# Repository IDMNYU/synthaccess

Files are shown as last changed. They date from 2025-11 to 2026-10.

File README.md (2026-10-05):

# synthaccess

#### syn?a3ess

A repository of research around and resources for synthesizer (and other audio technology) accessibility.

[ABILITY Project](http://ability.nyu.edu) / [Integrated Design & Media](http://idm.engineering.nyu.edu)   
New York University

Featuring the work of:
- [Ciarra Black](https://www.ciarrablack.com/)
- [Jason Dasent](https://www.jasondasent.com/)
- [R. Luke DuBois](https://lukedubois.com/), Faculty Lead, MIDI Speech Synth
- [Stefanie Koseff](https://www.stefaniekoseff.com/), Faculty Lead, Tactile Synth Guides
- [Tommy Martinez](https://thomasjohnmartinez.com/)
- [Madeline Mau](https://www.linkedin.com/in/madeline-mau-b01b9739b/)
- [Willie Payne](https://williepayne.com/)
- [Lauren Race](https://laurenrace.com/)
- [Izabella Rodrigues](https://www.izabellarodrigues.com/)
- [Jason Wallach](https://www.linkedin.com/in/jason-wallach-1340a612a/)
- [Moira Zhang](https://moirazhang.com/)

Projects:
- **[MIDItoSpeech](./MIDItoSpeech/)** : a speech synthesizer to vocalize parameters from a music technology device (synthesizer, effects processor, etc.) that transmits its state via MIDI.
- **[tactileSynthGuides](./tactileSynthGuides/)** : a design guide and library of swell-form printable tactile guides for synthesizers.
- **[brailleOverlays](./brailleOverlays/)** : guidelines for adding braille labels and overlays to physical synthesizers.
- **[tactileModular](./tactileModular/)** : a set of design resources for tactile affordances for modular synthesizers.

---

**SynthAccess** is a multi-pronged open source initiative around accessibility for Blind / Low Vision (BLV) musicians who use synthesizers and related equipment. This includes standards for braille labeling and tactile guides, software to generate synthesized speech as affordances are moved on the devices, and 3D printed alternatives to knobs and jacks to make them distinguishable by feel.

Modern music technology is challenging from an accessibility standpoint as it often features ocularcentric design patterns that use screens, LEDs to indicate state, and affordances such as rotary controls and soft buttons that only provide visual feedback.

For this project, we leverage two trends in synthesizer equipment: 
- Historical synthesizer designs employ *analog* circuitry, and have a design layout that is one affordance per function, which means that there are knobs, buttons, switches, sliders, and so forth that map to one specific parameter on the instrument. There are many modern synthesizers that either emulate this design approach or are recreations of historical equipment. This allows us to create overlay systems and tactile guides that allow a user to navigate a synthesizer user interface by touch.
- Modern synthesizers often employ microprocessors that *transmit the state* of their controls as they are being manipulated, typically using the MIDI protocol introduced in 1983 for digital communication among music technology equipment. This allows us to use computers and microcontrollers to listen to user actions performed on a synthesizer and create speech-based, haptic, refreshable braille, and other accessible interfaces without any change to the hardware.

Over the past year, we have developed a number of exemplar design interventions to assist BLV users with synthesizers. This work was undertaken as part of a larger initiative around making the [NYU Tandon IDM Audio Lab](https://idmnyu.github.io/audiolab/) accessible for users with disabilities, as well as work done in collaboration with the [FMDG Music School](https://fmdgmusicschool.org/) and a number of US music conservatories towards creating contemporary standards around music education for BLV students. In addition, we have been partnering with the [Focusrite Group](https://focusriteplc.com/) to adopt our standards to three of their synthesizer brands ([Sequential Circuits](https://sequential.com/), [Oberheim](https://oberheim.com/), and [Novation](http://novationmusic.com/)). We have also developed overlays for various other historical and contemporary synthesizers made by ARP, Roland, Nensén Electronics, and the Black Corporation.

We are interested in collaborating with industry partners and organizations to further develop our proposed designs and have them adopted as standards that could be integrated into the design and manufacturing stage for commercial synthesizers. We are also interested in further developing these tools for other music technology devices, and partnering with enthusiasts in the community to develop assets for vintage, open source, and DIY equipment.

We believe there is an opportunity to create strong consensus in the music technology industry that accessibility matters and can be viewed as a focal point of *collaboration*, not *competition*. To this end, this work is being published as free and open to the public under open-source software (MIT) and document copyright (CC BY-NC-SA 4.0) licenses.

If you're interested in working with us, please get in touch by writing Luke (dubois at nyu dot edu).

---

*A note to screen reader users:* some of the pages in this site use Grade 2 braille examples. These examples will be encoded in a way that may prevent a screen reader from reading them correctly. For example, the Grade 2 braille equivalent of **synthaccess** - this project's name - is <bl>syn?a3ess</bl>. In each case, a regular transliteration will be provided as well.

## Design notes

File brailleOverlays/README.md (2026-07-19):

# brailleOverlays

#### brlov}lays

Part of [synthaccess](../README.md)

[ABILITY Project](http://ability.nyu.edu) / [Integrated Design & Media](http://idm.engineering.nyu.edu)   
New York University

Files:
- README.md - this file
- [synths](https://github.com/IDMNYU/synthaccess/tree/main/brailleOverlays/synths) - folder containing vector synth overlays with braille mappings
    - [Human Comparator TTSH](https://raw.githubusercontent.com/IDMNYU/synthaccess/refs/heads/main/brailleOverlays/synths/TTSH.svg)
    - [Sequential Circuits Prophet 6 Desktop](https://raw.githubusercontent.com/IDMNYU/synthaccess/refs/heads/main/brailleOverlays/synths/Prophet6.svg)
- img - folder containing example images

**brailleOverlays** is a set of design guidelines and examples for adding braille lettering to synthesizers. 

## Introduction

If your synthesizer is "one affordance per function", one of the simplest and most effective ways to add tactile accessibility for Blind / Low Vision users is to label the synthesizer with braille. Below, we outline three methods (from simple and inexpensive to somewhat complex) for doing this.

[Braille](https://en.wikipedia.org/wiki/Braille) is a [standard](https://brailleauthority.org/size-and-spacing-braille-characters) tactile writing system invented in 1824 that uses a two column by three row grid of six dots for each character. The braille system not only specifies the layout of these dots for each character in the writing system, but also defines the characters' nominal dot sizing and spacing. In other words, there's no such thing as "winging it" when it comes to your braille size. There's just braille. With standard braille fonts, such as David Rakowski's [Braille TTF](https://www.1001fonts.com/braille-font.html) and [Swell Braille](https://www.ffonts.net/Swell-Braille.font.download), you can set your design software to 24 point and it will be within range. There are [standard mappings](https://en.wikipedia.org/wiki/International_uniformity_of_braille_alphabets) for common writing systems across the world. Languages that use logographic writing systems (such as [Chinese](https://en.wikipedia.org/wiki/Mainland_Chinese_Braille)) will use a phonetic alphabet to create a braille mapping.

Grade (or Level) 1 braille defines a [basic mapping](https://brailleaustralia.org/wp-content/uploads/2013/09/braillecharacters.pdf) for the alphabet, numbers, and punctuation. Grade 2 braille has [contractions](https://www.teachingvisuallyimpaired.com/uploads/1/4/1/2/14122361/ueb_braille_chart.pdf), leveraging context and unused characters to reduce common words, letter combinations, and syllables to fewer characters. Grade 1 braille is standardized by *character set* (e.g. the Roman alphabet versus Cyrillic), whereas Grade 2 braille is specific to the *language* being written (e.g. English vs. French). Free software such as [BrailleBlaster](https://www.brailleblaster.org/) can be used to convert text into braille that includes these Grade 2 contractions.

If you use Grade 2 braille, you can save space. For example, the phrase:

*"Some little children adding 2+2 might count it as 22, not 4."*

can be converted using Grade 2 braille to:

<bl>,"s ll *n add+ #b"6#b mi<t c.t x z #bb1 n #d4</bl>

<br>

This certainly saves space (46 characters instead of 61). However, a user who reads braille in a language other than English might not be able to read it.

## Option #1: Braille tape

The simplest way to add braille to a synthesizer is to use a low cost braille labeller (such as [this one](https://www.maxiaids.com/product/reizen-rl-350-braille-labeler)) and some adhesive-backed labeling tape (such as [this](https://www.amazon.com/NineLeaf-Compatible-3D-Embossing-Organizer/dp/B0C3MGZKYH/?th=1)). You can then punch out braille labels and apply them directly to your synthesizer's front panel. If you use clear labels, you can place the braille labels over the printed labels on the synthesizer. You can also create braille labels manually, using a [braille stylus](https://carroll.org/product/single-line-slate-w-stylus/) on dymo tape or any adhesive paper.

An alternative to this method is to print out sheets of braille on an embossing printer (such as [this one](https://viewplus.com/product/vp-columbia-2/#product-more-info)) using sticker paper, which you then cut out and affix to the device. You can use [BrailleBlaster](https://www.brailleblaster.org/) and the [Braille TTF](https://www.1001fonts.com/braille-font.html) typeface to experiment with this method.

Depending on the density of controls on your synthesizer, you may not be able to label everything (see [mappings](#mappings), below, on some ideas for shorthand). For synthesizers where it's not practicable to create a braille label for every single affordance, you could consider labelling the section headings of different areas of the synth (oscillator, filter, mixer, etc.), and then create a [tactile guide](../tactileSynths) to cover the details.

## Option #2: Labels on an overlay

While it's great to add labels directly to your equipment, two issues might occur. First, the synthesizer surface might not take well to adhesive labels (for example, if the face plate on the synthesizer is powder-coated metal). Second, you might be worried about the labels damaging your synthesizer (for example, if you have a vintage equipment where adhesives might cause wear on the visual labels underneath).

A great solution for all of this is to cut a **plexiglass overlay** for your synthesizer, and then affix the braille to the overlay. You can often make these overlays simply if you have access to a laser cutter; you can use pre-cut plexiglass (we use [0.040" clear colorless acrylic](https://www.canalplastic.com/products/clear-colorless-0-040-acrylic-sheet?variant=37615076302)) to make clear, thin sheets that can sit on top of the synthesizer's face, with holes cut in place for switches, buttons, knobs, etc.

The best overlays have ample space for all of the affordances (knobs, switches, sliders, jacks) on the synthesizer, but can still be affixed to the synth face in an easy manner. One way to do this is to add cutout points for the front panel mounting screws and make those circles small enough that you can use the screws to mount the plexi overlay and secure it it to the synth. Additionally, potentiometers often have knobs or slider caps that can be removed, so the cutout can be narrower, as it only needs to accommodate the shaft of the pot.

To make an overlay, there are a bunch of options:

1. Many commercial manufacturers provide line-art renderings of their front panels (on their websites, in PDF documentation, etc.) that can be imported into a vector design program (e.g. [Inkscape](https://inkscape.org/), Adobe Illustrator, CorelDRAW) and traced over to make a laser cuttable overlay. You can also write the manufacturer's support group and explain that you're making an accessibility overlay for one of their synths and would love a reference CAD file to work from - there's a good chance they'll help you out.
2. You can take a high resolution photograph of your synth and trace over it. Be careful for skewing / pincushioning artifacts from your camera not being face on with the synth.
3. You can use a 3D scanning app (such as Polycam or 3D Scanner App) to make a scan of your synthesizer's front panel and import it into 3D modelling software (such as [Blender](https://www.blender.org/)) that knows how to export a 2D vector slice of a 3D model. 2D vector software that knows how to create slices from 3D assets (Illustrator, Inkscape) can do this as well.
4. If the synthesizer is reasonably small, you can place it face-down on a scanner (or a photocopier with a scanning function). You can then create a layer and draw cutouts for your overlay.

With any of these methods, we recommend doing a test cut first on cardboard to make sure everything fits properly. Once you've got your overlay fitted, you can add your braille adhesive labels and they should stick well. As an added bonus, you now have a protective cover for your synthesizer!

## Option #3: UV Print the braille directly onto an overlay

If you're going to create an overlay for your synth, you can UV print the braille (as well as dividers and any other tactile graphics) onto the acrylic directly by using a commercial UV flatbed printer. Commercial print shops will often have UV printing service; for example, in the USA, if a print shop advertises that they can do "ADA signage", then you're probably in the right place. There may be print services in your community that are able to do a full-service project - they will source the acrylic, laser cut the overlay, and do the braille printing all in one go. It's our experience that many UV printers will typeset braille within their own software or work with design software customized for sign printing that knows how to typeset braille, such as [Flexi Design](https://www.thinksai.com/products-flexi-design/).

## Examples

The synthesizers we have created overlays for in the [IDM Audio Lab](https://idmnyu.github.io/audiolab/) are contained in the [synths](https://github.com/IDMNYU/synthaccess/tree/main/brailleOverlays/synths) folder of this repository as layered SVG files. 
1. The 'overlay' layer contain the laserable cutout.
2. The 'braille' layer contains braille labels in the [Braille TTF](https://www.1001fonts.com/braille-font.html) font. These labels can be made with a braile labeler, printed using an embossing printer, or directly printed onto an overlay using a UV printer.
3. The 'dividers' layer contains suggested dividers for different sections of the synthesizer. These can be made in a variety of ways; the simplest is to use the <bl>a</bl> / 'a' letter on a braille labeller and then turn the tape to the correct orientation. As with the above, you can also directly print this onto an overlay using a UV printer.

For example, here is the overlay developed by Moira Zhang for our [TTSH](https://idmnyu.github.io/audiolab/arp.html#ttsh) (a DIY ARP 2600 clone, developed by Jon Nensén).

This image shows the front panel of the TTSH:
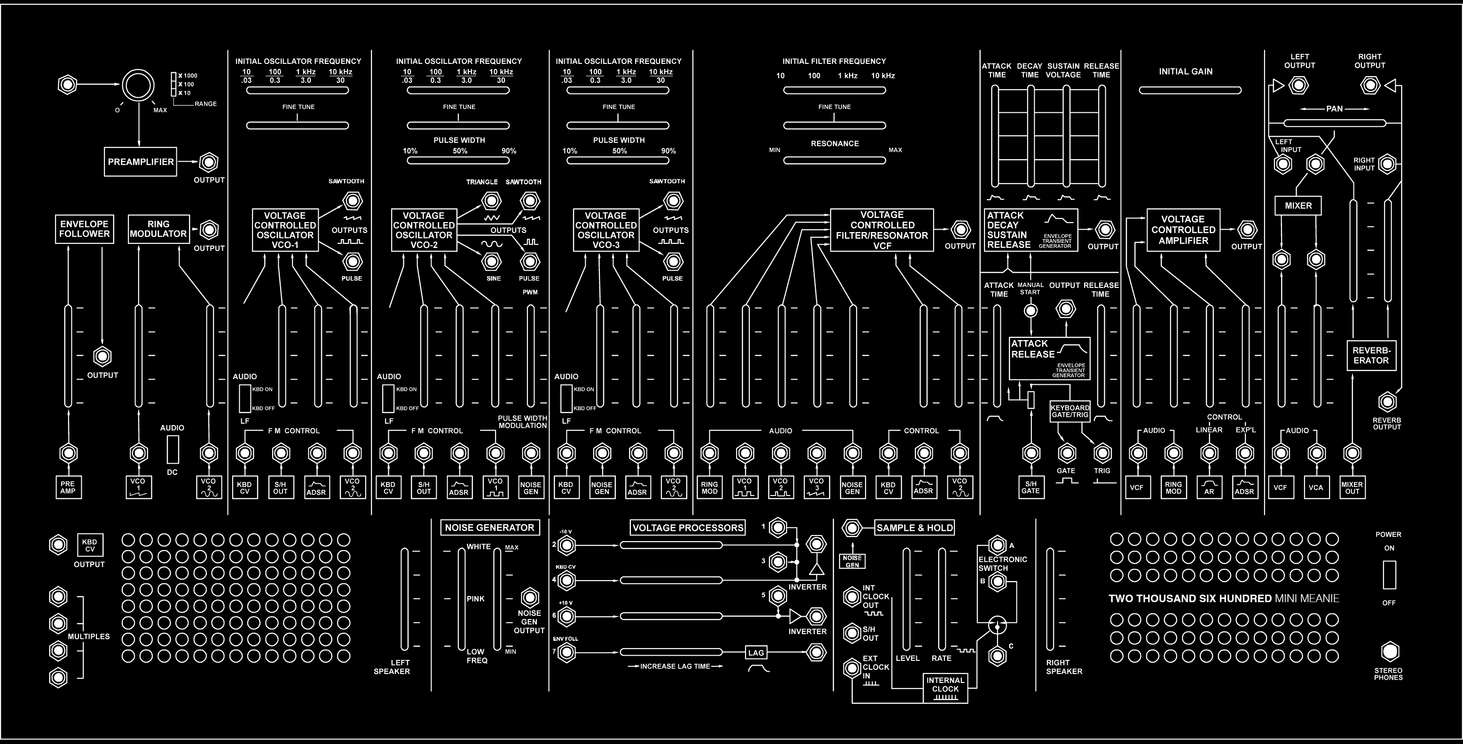
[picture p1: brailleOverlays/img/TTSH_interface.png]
TTSH visual interface

This image shows the full composite overlay of the TTSH, including interface channels, braille, and dividers:
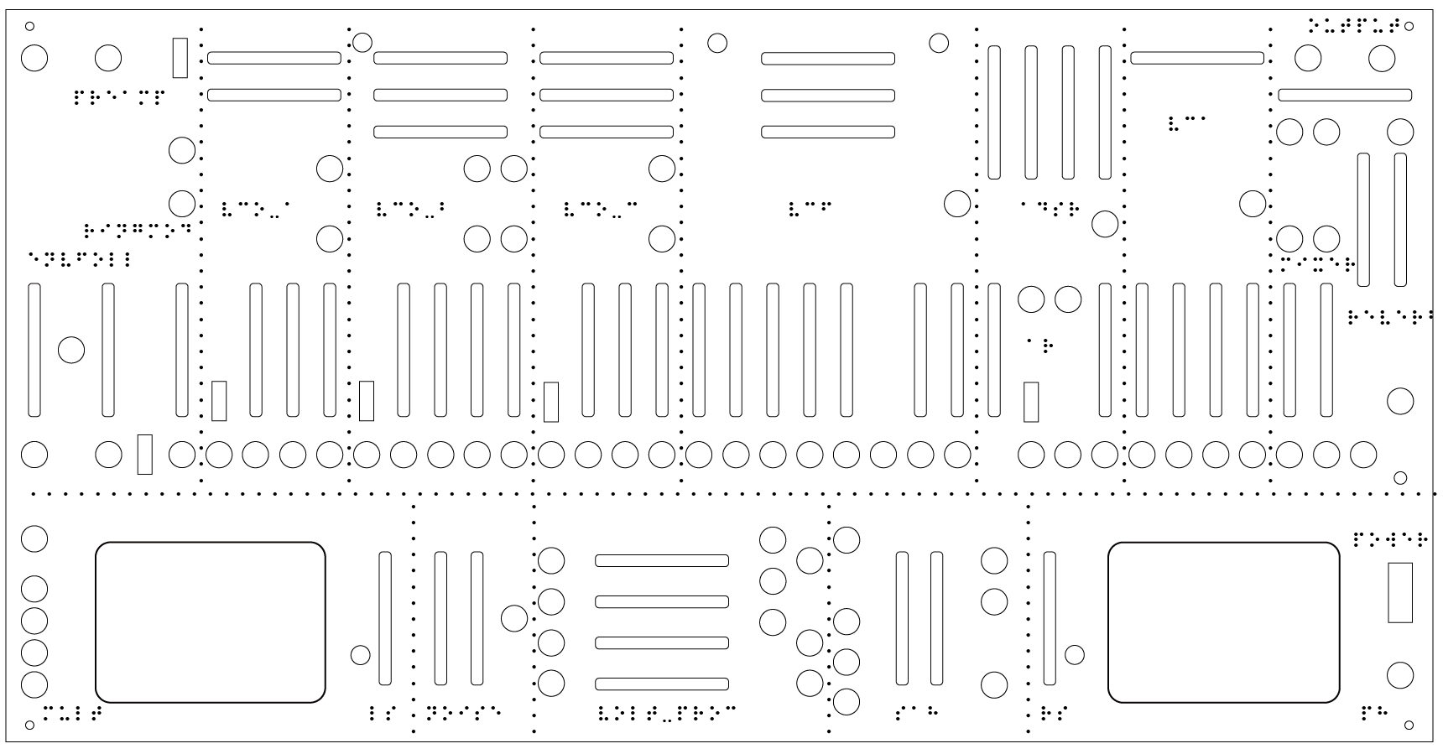
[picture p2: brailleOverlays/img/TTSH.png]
TTSH full overlay, with dividers and braille

This is the TTSH interface image used for laser cutting the overlay. Note the smaller circles - those are the front-panel screw points, not modular jacks - we used those to fix the overlay. We removed the knob for the microphone gain and the caps for the slide potentiometers before putting the panel on.
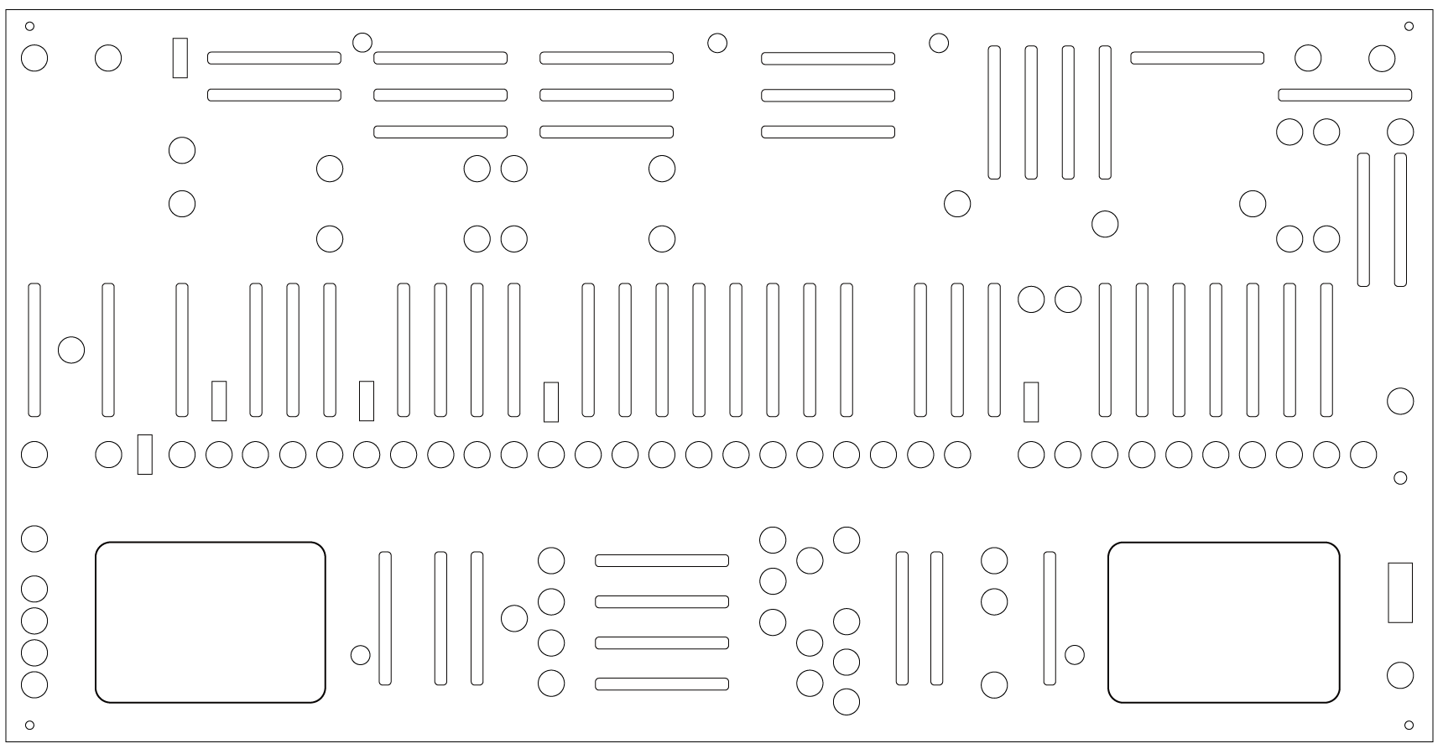
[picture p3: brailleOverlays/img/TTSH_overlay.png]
TTSH laser overlay

These are the TTSH braille labels by themselves. You could use a braille labeller to make these.
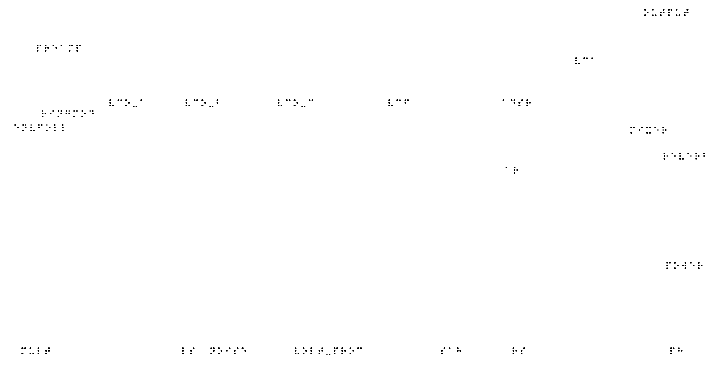
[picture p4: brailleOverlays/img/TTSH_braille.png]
TTSH braille labels

Finally, these show divider labels for the TTSH made using braille dots. You can make a long adhesive line of them, cut them to size with scissors, and apply them to give a tactile sense of the boundaries between the different modules on the synth.
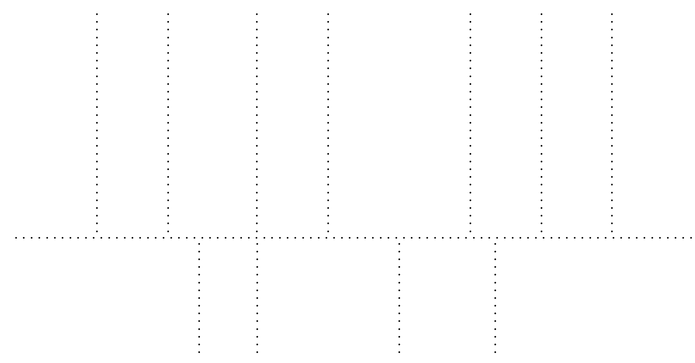
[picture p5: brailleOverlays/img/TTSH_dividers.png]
TTSH divider labels


If you would like to contribute to this project or have an overlay file you've done, please get in touch.

## Suggested Mappings

When designing braille overlays for physical synthesizers, space may be at a premium, so shorhands, abbreviations, contractions, and use of Grade 2 braille will be super useful for labelling things. Below are some suggested mappings for common synthesizer controls if you have space for 2, 3, or 4 braille characters. 

As mentioned above, for more high density interfaces, a great solution is to create a tactile guide. The [tactileSynths](../tactileSynths) part of this repository will help you get started.

### General Synthesizer Terminology

| Label | 2 | 3 | 4 |
| ----- | ----- | ----- | ----- |
| <bl>p{}</bl><br>Power | <bl>pr</bl><br>pr | <bl>pwr</bl><br>pwr | <bl>powr</bl><br>powr |
| <bl>h1dph"os</bl><br>Headphones | <bl>ph</bl><br>ph |  | <bl>phns</bl><br>phns |
| <bl>voltage-3troll$ oscillator</bl><br>Voltage-Controlled Oscillator | <bl>vo</bl><br>vo | <bl>vco</bl><br>vco | |
| <bl>voltage-3troll$ filt}</bl><br>Voltage-Controlled Filter | <bl>vf</bl><br>vf | <bl>vcf</bl><br>vcf |  |
| <bl>voltage-3troll$ amplifi}</bl><br>Voltage-Controlled Amplifier | <bl>va</bl><br>va | <bl>vca</bl><br>vca |  |
| <bl>l{ frequ5cy oscillator</bl><br>Low Frequency Oscillator | <bl>lf</bl><br>lf | <bl>lfo</bl><br>lfo |  |
| <bl>s9e wave</bl><br>Sine Wave | <bl>sn</bl><br>sn | <bl>s9e</bl><br>sine |  |
| <bl>triangle wave</bl><br>Triangle Wave | <bl>tr</bl><br>tr | <bl>tri</bl><br>tri |  |
| <bl>sawtoo? wave</bl><br>Sawtooth Wave | <bl>sa</bl><br>sa | <bl>saw</bl><br>saw |  |
| <bl>squ>e wave</bl><br>Square Wave | <bl>sq</bl><br>sq | <bl>sqr</bl><br>sqr |  |
| <bl>noise generator</bl><br>Noise Generator | <bl>no</bl><br>no | <bl>noi</bl><br>noi | |
| <bl>attack rel1se</bl><br>Attack Release | <bl>ar</bl><br>ar | | |
| <bl>attack decay su/a9 rel1se</bl><br>Attack Decay Sustain Release | | | <bl>adsr</bl><br>adsr |
| <bl>5velope g5}ator</bl><br>Envelope Generator | <bl>eg</bl><br>eg | <bl>env</bl><br>env |  |
| <bl>sample & hold</bl><br>Sample and Hold | <bl>sh</bl><br>sh | <bl>sah</bl><br>sah | |
| <bl>syn*ronize</bl><br>Synchronize | <bl>sy</bl><br>sy | <bl>syn</bl><br>syn | <bl>sync</bl><br>sync |
| <bl>5velope foll{}</bl><br>Envelope Follower | <bl>ef</bl><br>ef | <bl>efl</bl><br>efl |<bl>enfl</bl><br>enfl |
| <bl>r+ modulator</bl><br>Ring Modulator | <bl>rm</bl><br>rm | <bl>r+m</bl><br>ringm |<bl>r+md</bl><br>ringmd |
| <bl>mix}</bl><br>Mixer | <bl>mx</bl><br>mx | <bl>mxr</bl><br>mxr |<bl>mix}</bl><br>mixer |
| <bl>frequ5cy</bl><br>Frequency | <bl>fr</bl><br>fr | <bl>frq</bl><br>frq |<bl>freq</bl><br>freq |
| <bl>filt}</bl><br>Filter | <bl>fi</bl><br>fi | <bl>fil</bl><br>fil |<bl>fltr</bl><br>fltr |
| <bl>l{ pass filt}</bl><br>Low Pass Filter | <bl>lp</bl><br>lp | <bl>lpf</bl><br>lpf | |
| <bl>hi< pass filt}</bl><br>High Pass Filter | <bl>hp</bl><br>hp | <bl>hpf</bl><br>hpf | |
| <bl>b& pass filt}</bl><br>Band Pass Filter | <bl>bp</bl><br>bp | <bl>bpf</bl><br>bpf | |
| <bl>not* filt}</bl><br>Notch Filter | <bl>nf</bl><br>nf | | <bl>not*</bl><br>notch |

### Serge Modular Names

Serge Modular systems have specific acronyms and abbreviations for canonical modules (as seen in e.g. the [1983 sales catalog](https://docs.google.com/viewer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)) that are short enough to be used as braille labels. A mapping table is below.

**1973-75 "Paperface" Modules:**

| Module | Label |
| ----- | ----- |
| Adapter | <bl>adp</bl><br>ADP |
| Dual Processor | <bl>prc</bl><br>PRC |
| Envelope Generator | <bl>env</bl><br>ENV |
| Filter | <bl>vcf</bl><br>VCF |
| Gate | <bl>vca</bl><br>VCA |
| Negative Slew | <bl>neg</bl><br>NEG |
| Noise Source | <bl>noi</bl><br>NOI |
| Oscillator | <bl>vco</bl><br>VCO |
| Peak & Trough | <bl>p&t</bl><br>P&T |
| Preamp | <bl>pre</bl><br>PRE |
| Reverb | <bl>rvb</bl><br>RVB |
| Positive Slew | <bl>pos</bl><br>POS |
| Programmer | <bl>prg</bl><br>PRG |
| Ring Modulator | <bl>r+</bl><br>RING |
| Sequencer | <bl>seq</bl><br>SEQ |
| Smooth Function / Stepped Function VC Generator | <bl>ssg</bl><br>SSG |
| (Triple) Bi-Directional Router | <bl>tbs</bl><br>TBS |
| (Triple) Comparator | <bl>com</bl><br>COM |
| Triple Waveshaper | <bl>tws</bl><br>TWS |

**3rd/4th Generation Modules:**

| Module | Label |
| ----- | ----- |
| Active Processor | <bl>acpr</bl><br>ACPR |
| Analog Shift Register | <bl>asr</bl><br>ASR |
| Control Module | <bl>c/m</bl><br>C/M |
| Divide-by-N Comparator | <bl>ncom</bl><br>NCOM |
| Dual 3-Input Audio Mixer | <bl>mix</bl><br>MIX |
| Dual Channel Stereo Mixer | <bl>dcsm</bl><br>DCSM |
| Dual Schmitt Trigger | <bl>str</bl><br>STR |
| Dual Stereo Panner Channel | <bl>pan</bl><br>PAN |
| Dual Universal Slope Generator | <bl>dsg</bl><br>DSG |
| Dual VC Phaser | <bl>2pha</bl><br>2PHA |
| Dual VC Transient Generator | <bl>dtg</bl><br>DTG |
| Dual VCA | <bl>2vca</bl><br>2VCA |
| Envelope Detector | <bl>env</bl><br>ENV |
| Extended ADSR Envelope Generator | <bl>adsr</bl><br>ADSR |
| Extended Range VCFQ  | <bl>vcfs</bl><br>VCFX |
| Four Input Stereo Mixer/Panner | <bl>mxp</bl><br>MXP |
| Frequency Shifter | <bl>frs</bl><br>FRS |
| Matrix Mixer  | <bl>max</bl><br>MAX |
| Multi-Channel Quadraphonic Mixer | <bl>qmx</bl><br>QMX |
| Multi-Channel Stereo Panner | <bl>stx</bl><br>STX |
| N-Voice Controller | <bl>nvc</bl><br>NVC |
| New Timbral Oscillator | <bl>nto</bl><br>NTO |
| Pitch and Envelope Follower | <bl>pef</bl><br>PEF |
| Preamp Detector | <bl>prnv</bl><br>PRNV |
| Precision VCO | <bl>pco</bl><br>PCO |
| Quad Panner Channel  | <bl>qpc</bl><br>QPC |
| Quantizer | <bl>quan</bl><br>QUAN |
| Random Source | <bl>rs</bl><br>RS |
| Random Voltage Generator | <bl>rvg</bl><br>RVG |
| Resonant Equalizer | <bl>eq</bl><br>EQ |
| Scaling Buffer | <bl>buff</bl><br>BUFF |
| Scaling Processor | <bl>sprc</bl><br>SPRC |
| Sequencer Programer | <bl>sqp4</bl><br>SQP |
| Touch Activated Keyboard Sequencer | <bl>tkb</bl><br>TKB |
| Universal Audio Processor  | <bl>uap</bl><br>UAP |
| Variable Q VC Filter | <bl>vcfq</bl><br>VCFQ |
| Variable Bandwidth VC Filter | <bl>vcf2</bl><br>VCF2 |
| Variable Slope VC Filter | <bl>vcfs</bl><br>VCFS |
| VC Cross-Fader  | <bl>xfad</bl><br>XFAD |
| VC Phaser | <bl>pha</bl><br>PHA |
| VC Quadrature Oscillator | <bl>quo</bl><br>QUO |
| VC Wave Multipliers | <bl>vcm</bl><br>VCM |
| VC Stereo Mixer | <bl>vcsm</bl><br>VCSM |
| Wilson Analog Delay | <bl>wad</bl><br>WAD |

## Gallery

TTSH & DIY 1601 Sequencer with braille
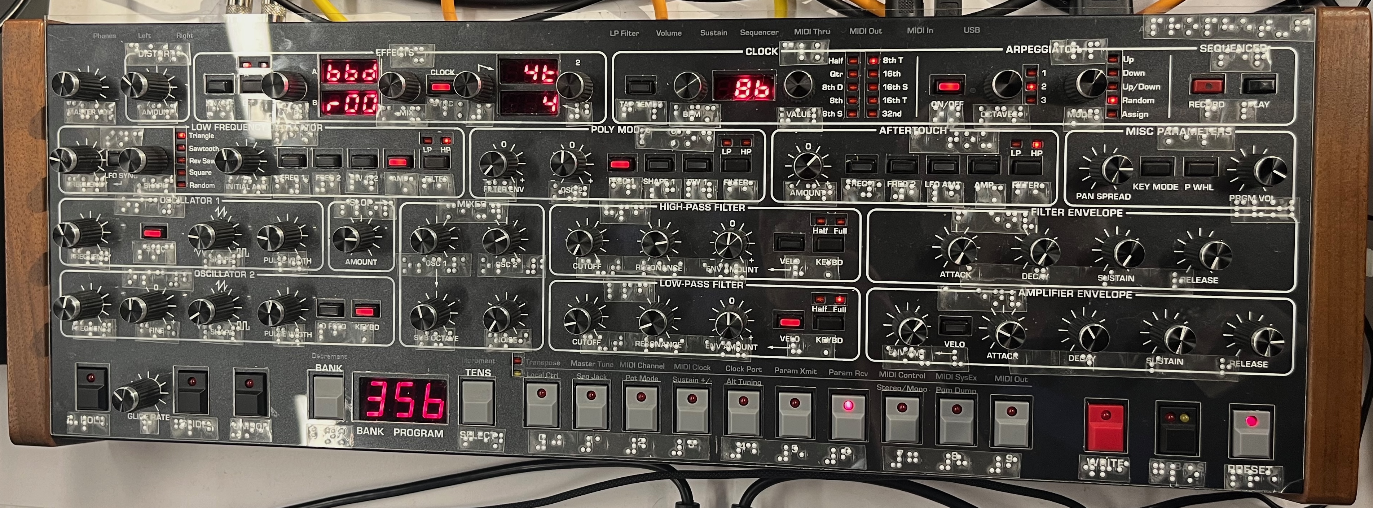
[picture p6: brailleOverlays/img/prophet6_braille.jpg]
Sequential Prophet 6 module with braille

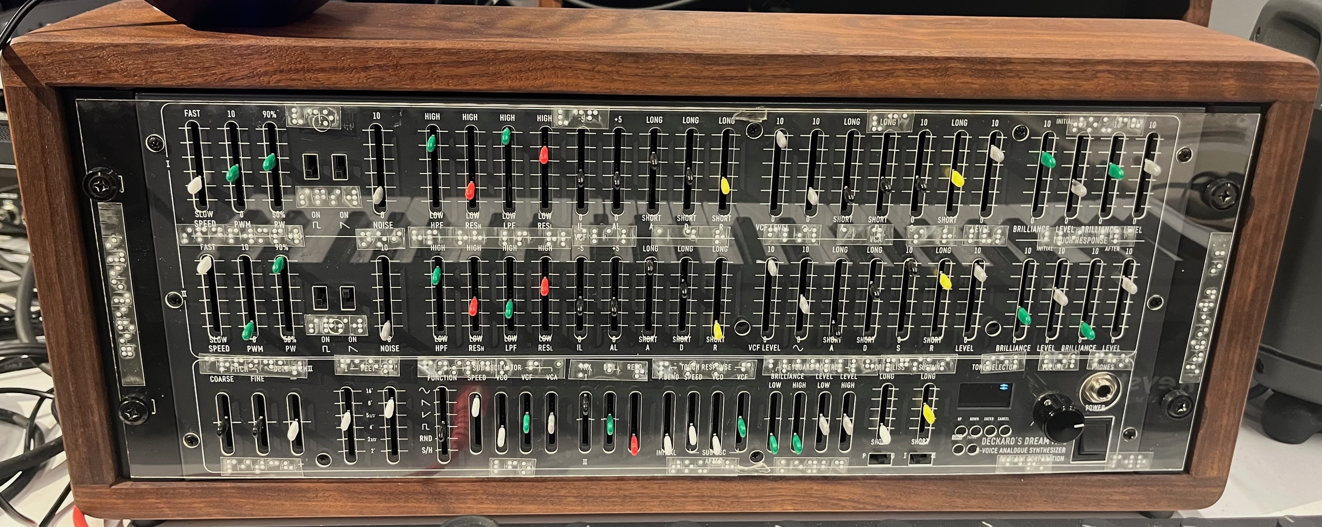
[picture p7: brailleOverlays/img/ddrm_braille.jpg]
Black Corporation Deckard's Dream with braille

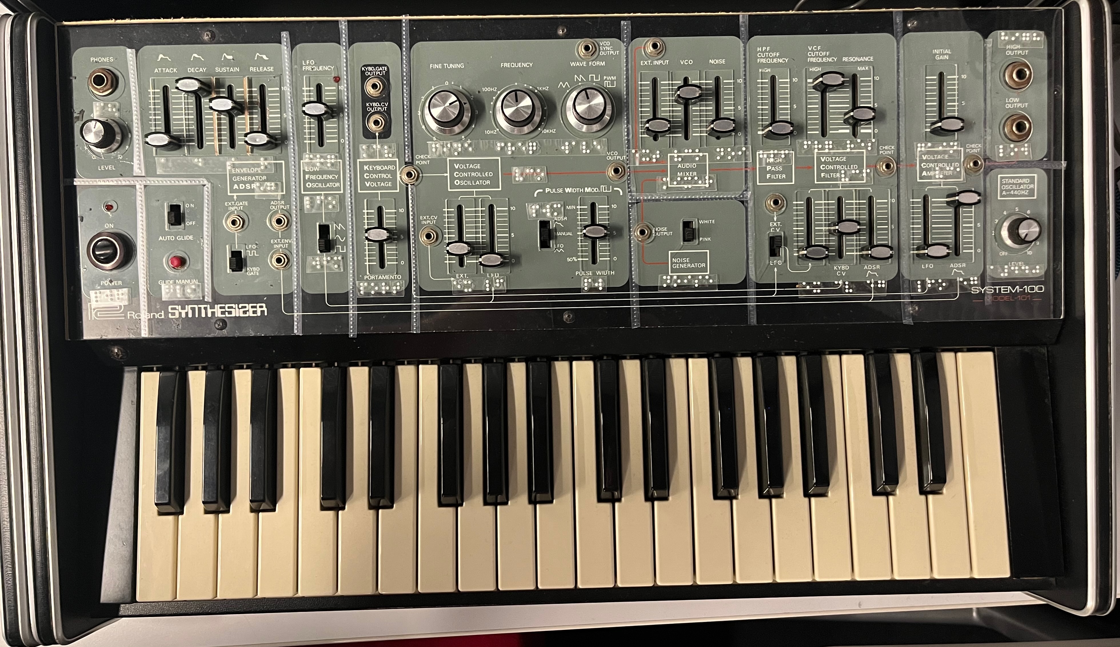
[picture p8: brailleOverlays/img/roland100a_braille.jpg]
Roland 100 Series Model 101 with braille

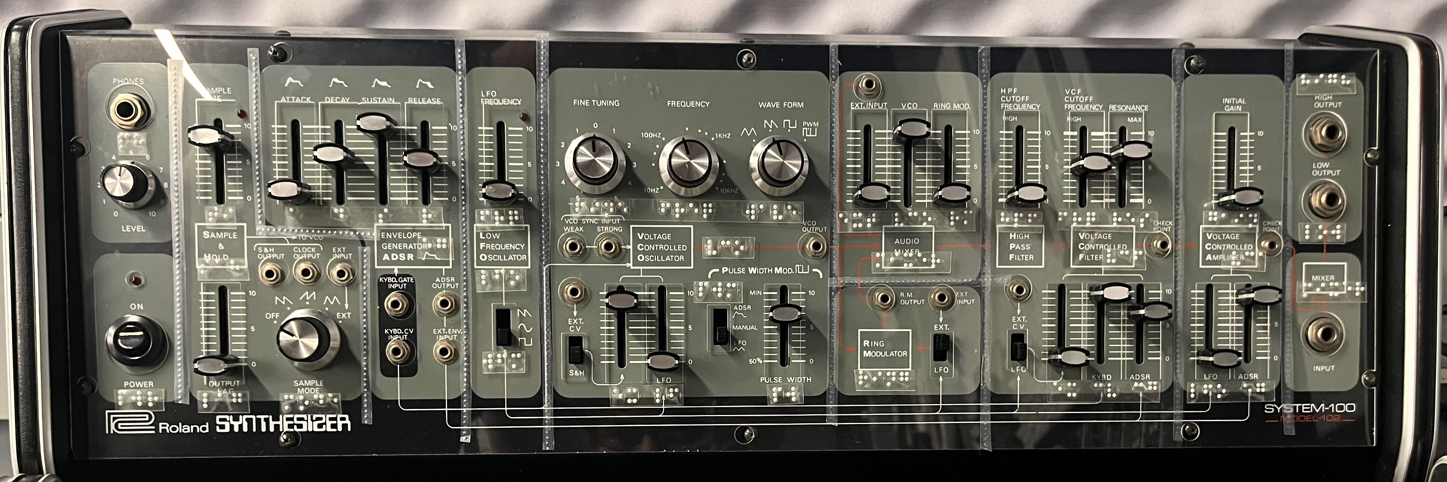
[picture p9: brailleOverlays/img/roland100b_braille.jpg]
Roland 100 Series Model 102 with braille

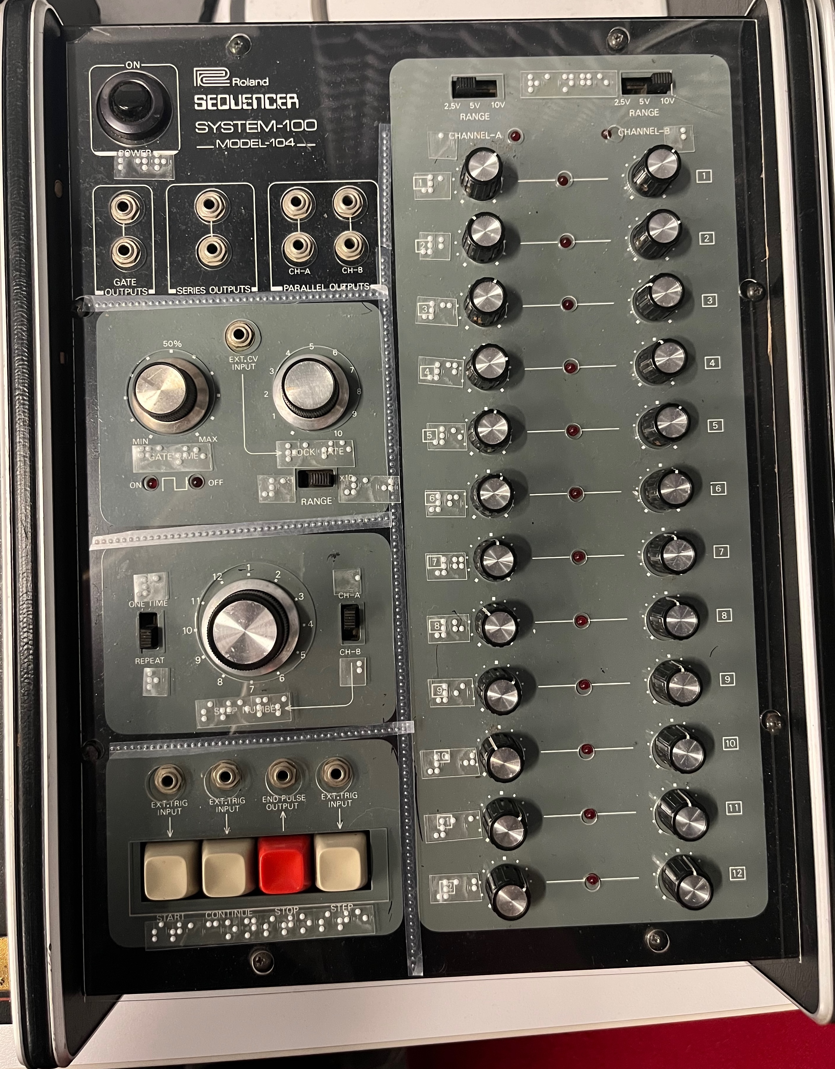
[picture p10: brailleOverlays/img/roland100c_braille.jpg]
Roland 100 Series Model 104 with braille

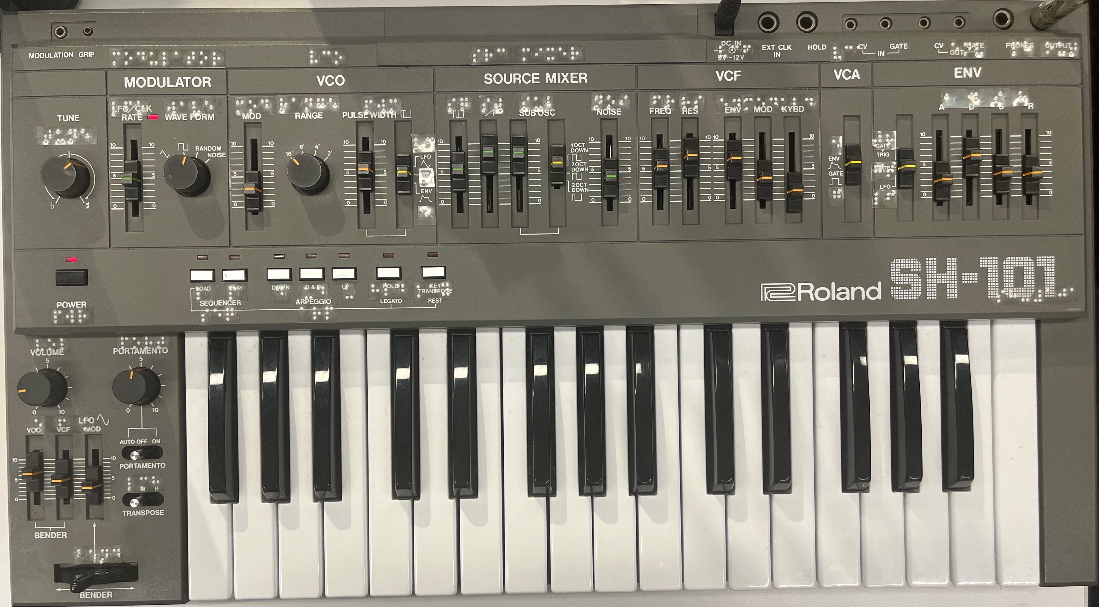
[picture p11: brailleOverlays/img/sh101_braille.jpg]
Roland SH-101 with braille


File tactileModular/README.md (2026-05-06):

# tactileModular

#### tactilemodul>

Part of [synthaccess](../README.md)

[ABILITY Project](http://ability.nyu.edu) / [Integrated Design & Media](http://idm.engineering.nyu.edu)   
New York University

Files:
- README.md - this file
- [Serge](https://github.com/IDMNYU/synthaccess/tree/main/tactileModular/Serge) - 3D files for the Serge modular system

Resources for tactile affordances specific to modular synthesizers. 

### Serge

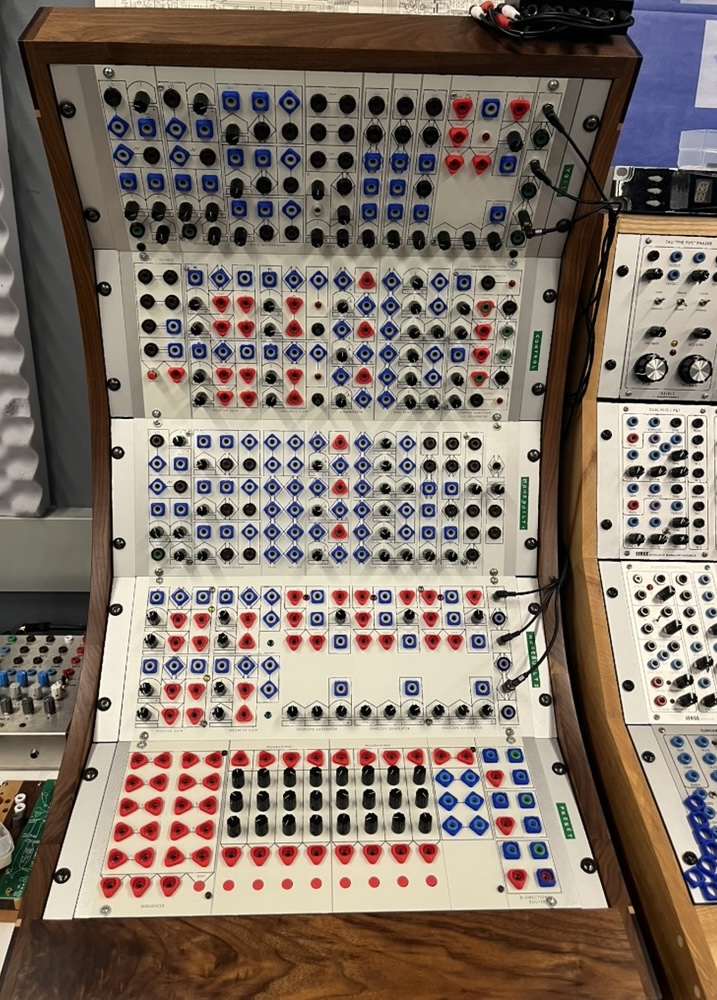
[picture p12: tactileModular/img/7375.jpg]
73-75 Serge Modular system with tactile affordances


The *Serge* folder contains a collection of Serge modular jack collars and knob designs by Jason Wallach to allow for tactile sensing of the different affordances on Serge Modular (and related "4U" banana-jack modular) equipment. The repository contains both [STL](https://en.wikipedia.org/wiki/STL_(file_format)) and [STEP](https://en.wikipedia.org/wiki/ISO_10303-21) files that can be used with most 3D printers.

- In our mapping, AC signal jacks have circular collars, DC signal jacks have square collars, and Pulse jacks have triangular collars. Miscellaneous jacks (such as the coupler output on an SSG module) have hexagonal collars.
- The *output* jacks are flat and should fit flush onto the standard Pomona jacks used on most Serge and other 4U synthesizers.
- The *input* jacks are deeper and have rounded "calderas"; in addition to providing a tactile distinction from the output jacks, they (lightly) disincentivize the stacking of banana cables at inputs.

| Jack Type  | Color | Image | Render | STL file | STEP file |
| --- | ----- | ----- | -- | --- | --- |
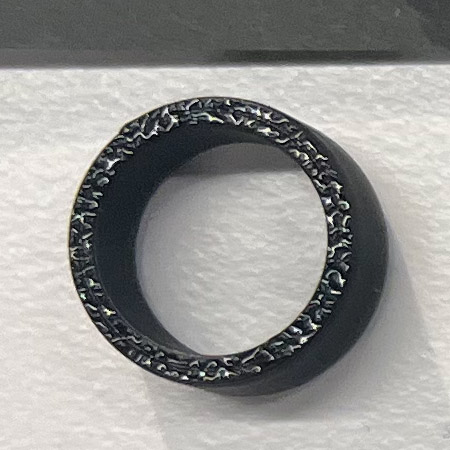
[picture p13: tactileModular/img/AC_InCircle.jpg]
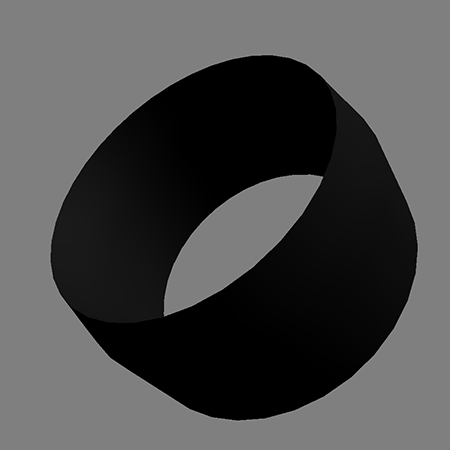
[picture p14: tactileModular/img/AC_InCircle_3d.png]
| AC Input | Black/Brown |  |  | AC_InCircle.stl | AC_InCircle.step |
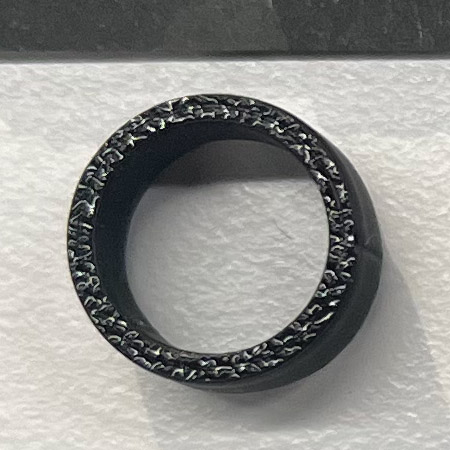
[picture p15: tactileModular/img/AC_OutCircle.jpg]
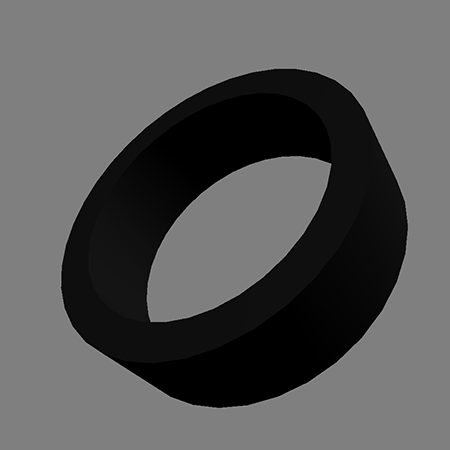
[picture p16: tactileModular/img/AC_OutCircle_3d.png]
| AC Output | Black/Brown |  |  | AC_OutCircle.stl | AC_OutCircle.step |
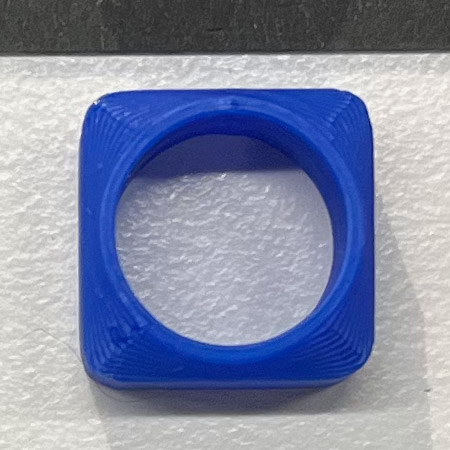
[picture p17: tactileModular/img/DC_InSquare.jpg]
blue square with caldera
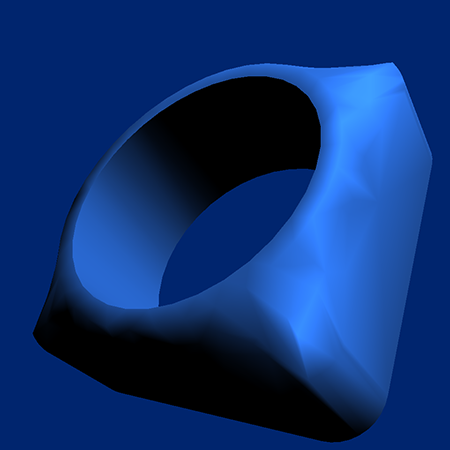
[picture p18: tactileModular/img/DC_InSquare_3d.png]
blue square with caldera
| DC Input | Blue/Grey |  |  | DC_InSquare.stl | DC_InSquare.step |
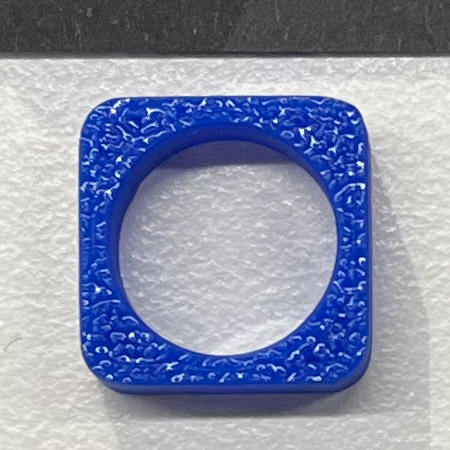
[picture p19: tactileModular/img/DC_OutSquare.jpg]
blue square
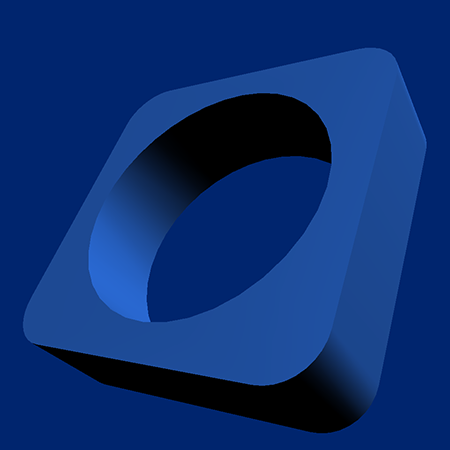
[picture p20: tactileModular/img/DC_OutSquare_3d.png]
blue square
| DC Output | Blue/Grey |  |  | DC_OutSquare.stl | DC_OutSquare.step |
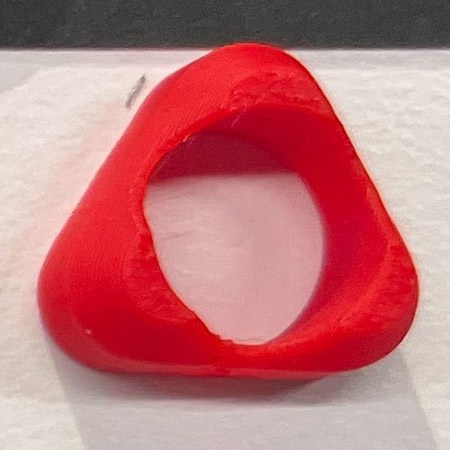
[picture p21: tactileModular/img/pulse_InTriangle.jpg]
red triangle with caldera
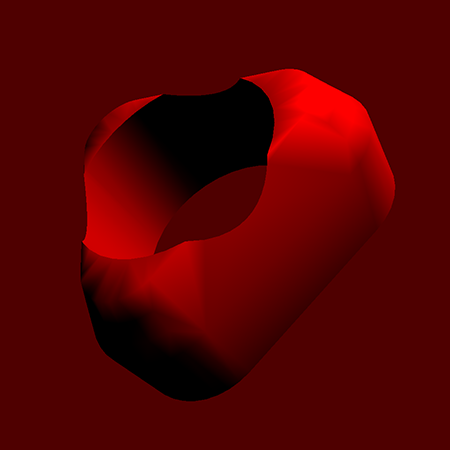
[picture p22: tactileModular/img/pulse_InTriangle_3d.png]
red triangle with caldera
| Pulse Input | Red |  |  | DC_InSquare.stl | DC_InSquare.step |
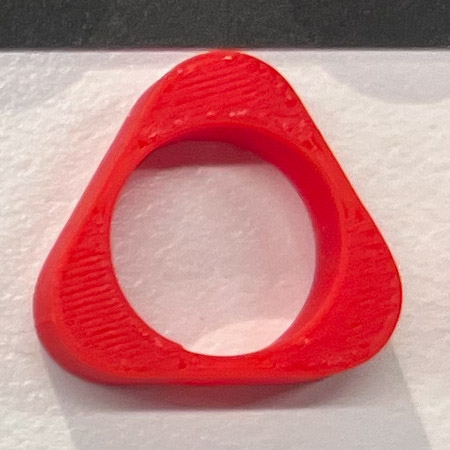
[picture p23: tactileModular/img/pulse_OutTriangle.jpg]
red triangle
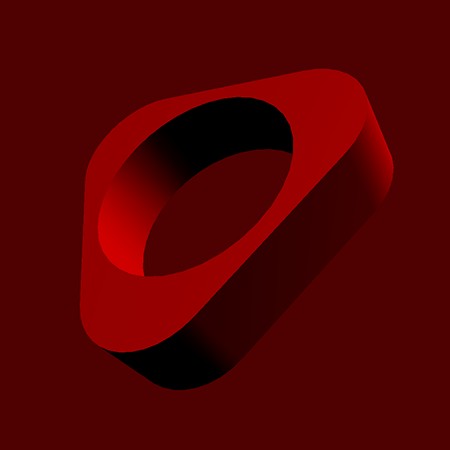
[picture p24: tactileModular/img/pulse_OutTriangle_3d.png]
red triangle
| Pulse Output | Red |  |  | DC_OutSquare.stl | DC_OutSquare.step |
| Misc Input | Various | gray hexagon with dots | gray hexagon with dots | misc_InHexagon.stl | misc_InHexagon.step |
| Misc Output | Various | gray hexagon | gray hexagon | misc_OutHexagon.stl | misc_OutHexagon.step |

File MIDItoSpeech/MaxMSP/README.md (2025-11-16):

## MIDItospeech (MAX PATCH VERSION)

This software requires [Max 9](https://cycling74.com/) and the the [MaxEss objects](https://www.if-tah.com/devices/maxess
).

The devices folder symlinks to the JSON files one level above in the repository (shared with the Web version).

The patcher is designed to be navigated entirely with keystrokes:

- up/down : cycle through the list of device files found in the 'devices' folder.
- j : load a JSON device file directly; an accessible file browser will open.
- escape : rescan the MIDI ports on your computer
- left/right : cycle through available MIDI input ports
- shift-left/shift-right : cycle through available MIDI output ports
- c : cycle through the active MIDI channel for the device
- r : toggle the voiceover rate between fast and normal
- tabe : toggle the speech synthesizer off and on
- i : read instructions through the speech synthesizer

other keys can be mapped in the JSON.

rld, 2025

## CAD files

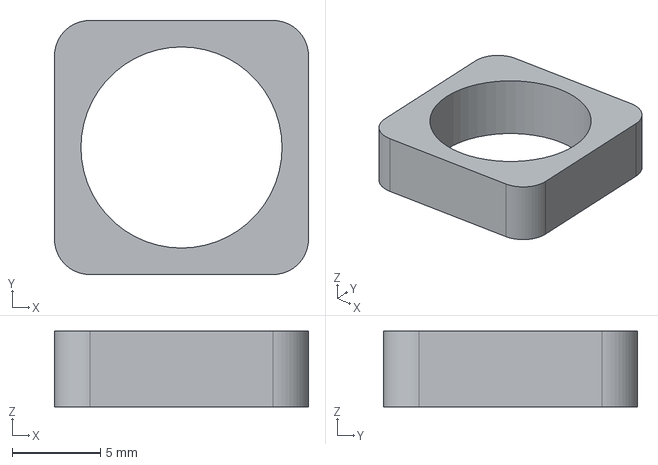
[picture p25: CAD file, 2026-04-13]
tactileModular/Serge/DC_OutSquare.step
14.4 x 14.4 x 4.30 mm

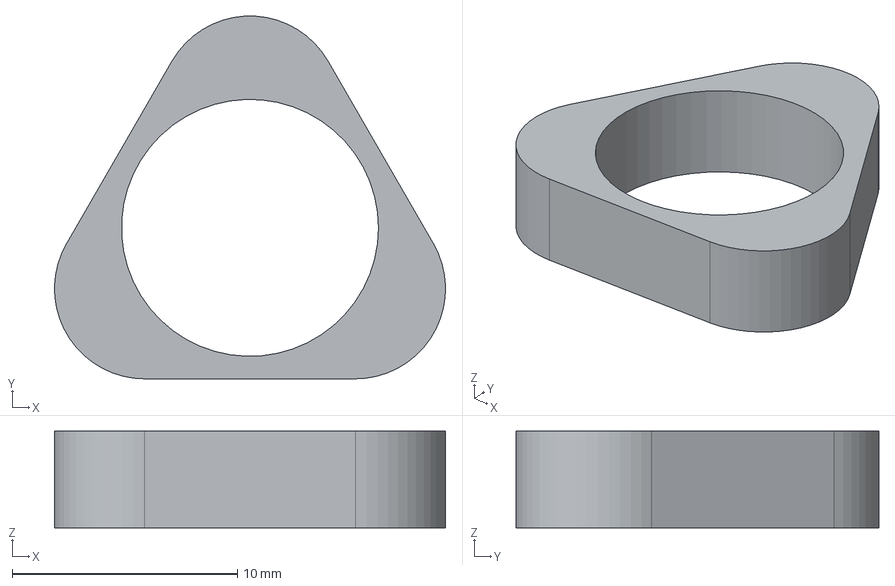
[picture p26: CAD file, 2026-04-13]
tactileModular/Serge/pulse_OutTriangle.step
17.3 x 16.1 x 4.30 mm

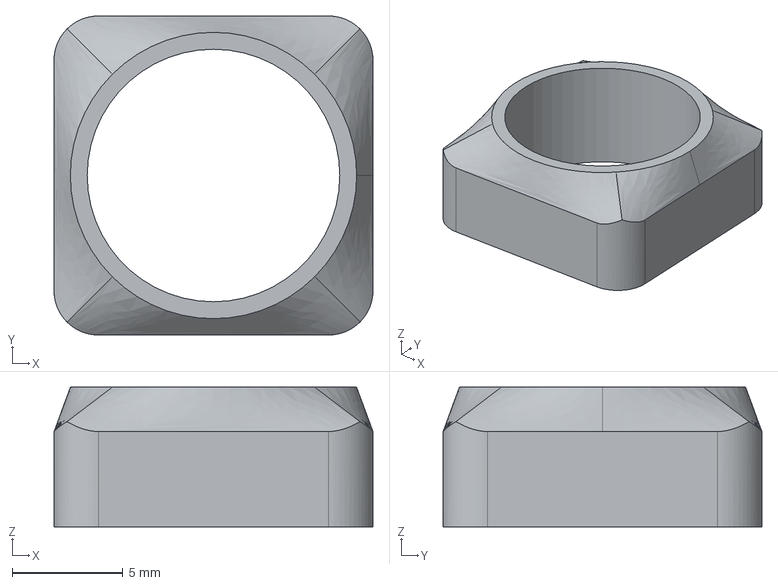
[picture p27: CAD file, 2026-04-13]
tactileModular/Serge/DC_InSquare.step
14.4 x 14.4 x 6.30 mm

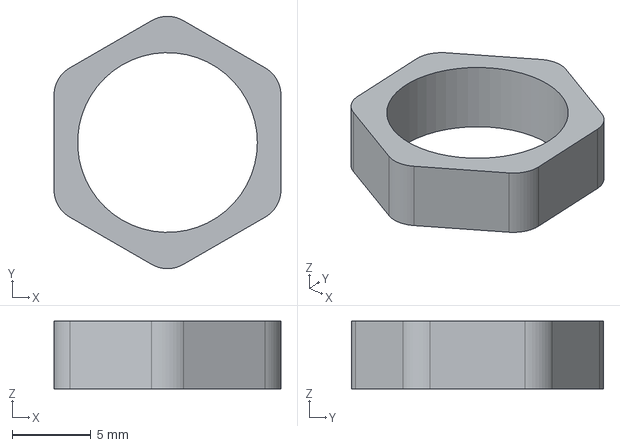
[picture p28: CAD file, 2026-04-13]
tactileModular/Serge/misc_OutHexagon.step
14.4 x 16.0 x 4.30 mm

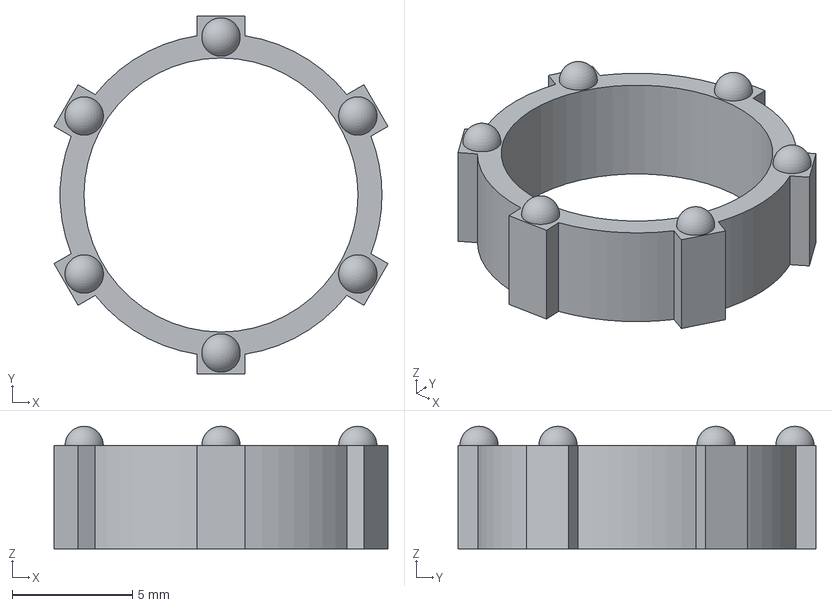
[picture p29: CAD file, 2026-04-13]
tactileModular/Serge/misc_InHexagon.step
13.9 x 14.9 x 5.10 mm

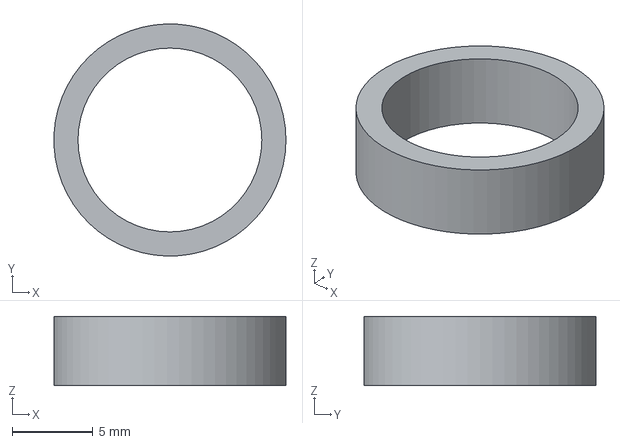
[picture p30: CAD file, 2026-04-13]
tactileModular/Serge/AC_OutCircle.step
14.4 x 14.4 x 4.30 mm

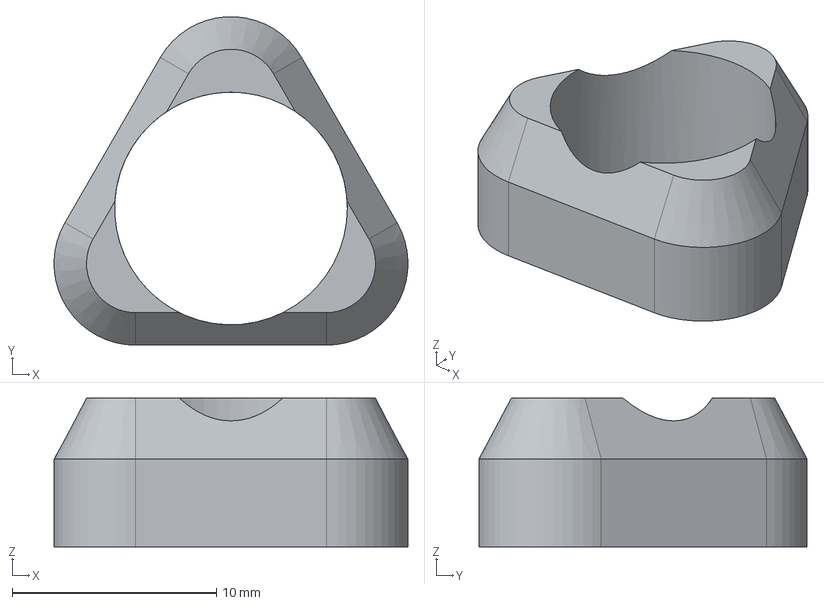
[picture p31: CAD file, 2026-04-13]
tactileModular/Serge/pulse_InTriangle.step
17.3 x 16.1 x 7.30 mm

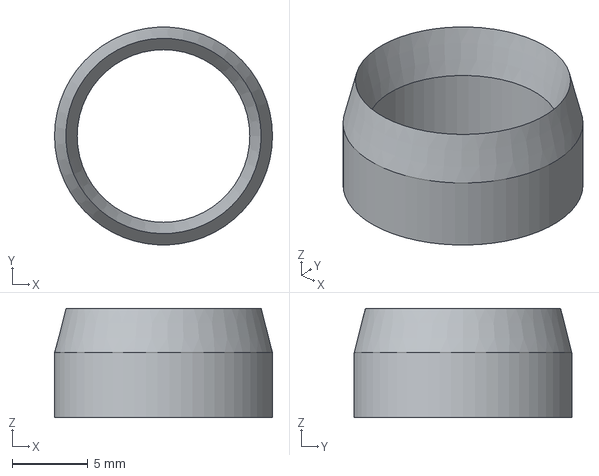
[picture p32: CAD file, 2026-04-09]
tactileModular/Serge/AC_InCircle.step
14.4 x 14.4 x 7.23 mm

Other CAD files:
tactileModular/Serge/AC_InCircle.stl
tactileModular/Serge/AC_OutCircle.stl
tactileModular/Serge/DC_InSquare.stl
tactileModular/Serge/DC_OutSquare.stl
tactileModular/Serge/misc_InHexagon.stl
tactileModular/Serge/misc_OutHexagon.stl
tactileModular/Serge/pulse_InTriangle.stl
tactileModular/Serge/pulse_OutTriangle.stl

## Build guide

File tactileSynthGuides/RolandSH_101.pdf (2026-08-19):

## Roland System SH-101

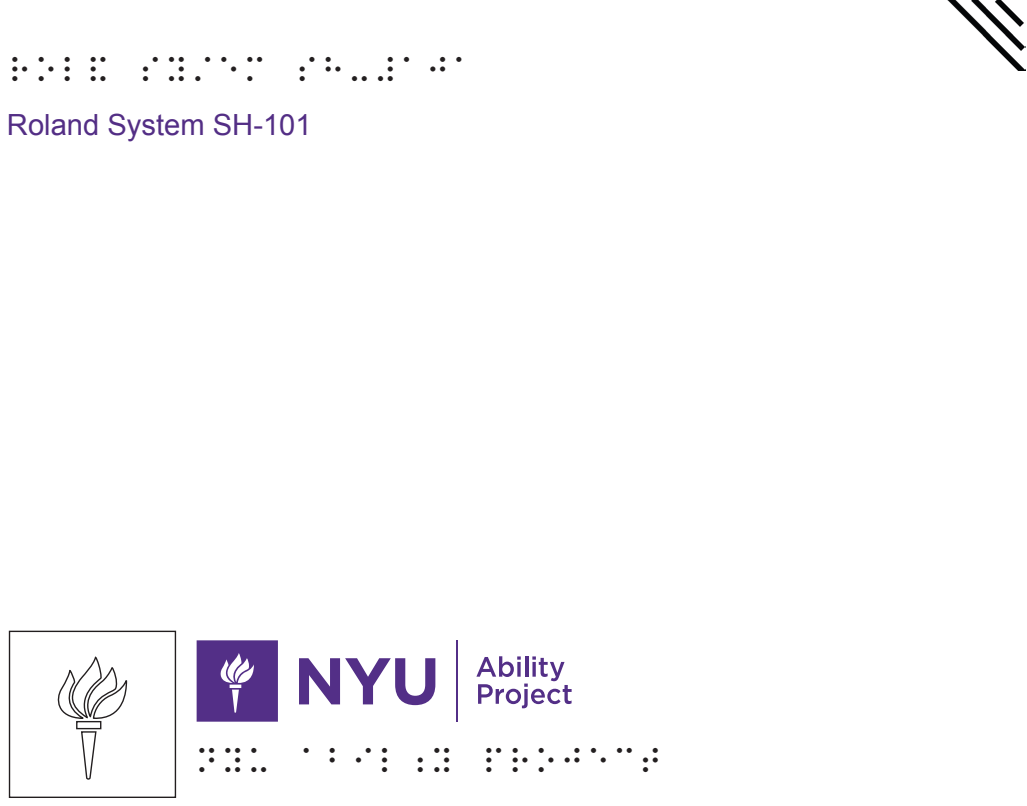
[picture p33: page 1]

rol& sy/em sh-#aja

nyu abil;y project

## Tactile Synths NYU Ability Project / IDM

Created by:
Stefanie Koseff, Faculty Lead Madeline Mau
Moira Zhang
Ciarra Black
Izabella Rodrigues
Jason Wallach
Lauren Race
R. Luke DuBois, Faculty Advisor

tactile syn?s
nyu abil;y project
_/ idm

created by:
stefanie koseff,
faculty lead
madeline mau
moira zhang
ciarra black
izabella rodrigues
jason wallach
lauren race
r. luke dubois,
faculty advisor tactile syn?s ~c #bjbe new york univ}s;y is lic;ed "u cc by-nc-sa #d4j4 ,to view a copy ( ? lic;e¹ visit
https³_/_/cr¹tivecommons4org_/li c5ses_/by-nc-sa_/#d4j_/

,"p ( ! syn? a³ess project4 ,git,hub³
https³_/_/gi?ub4com_/idmnyu_/syn?a³ess

Tactile Synths © 2025 New York University is licenced under CC BY-NC-SA 4.0.
To view a copy of this licence, visit
https://creativecommons.org/licenses/by-nc-sa/4.0/

Part of the Synth Access Project.
GitHub: https://github.com/IDMNYU/synthaccess

key | Key:
|tput | Output

9put Input

bidirec;nal jack | Bidirectional Jack
v}tical slid} | Vertical Slider

horizontal slid} Horizontal Slider

or | swit* | Switch
or

Key: Key:

knob Knob

button Button

Square Button

Power Switch

squ>e button

p{} swit*

Key: Key:

SW - Rising Saw

tri - triangle TRI - Triangle

s9e Sine

adsr ADSR

Gate

pls - pulse

sq - squ>e

PLS - Pulse

SQ - Square

sw - ris+ saw

gate

## modula;n grip Modulation Grip

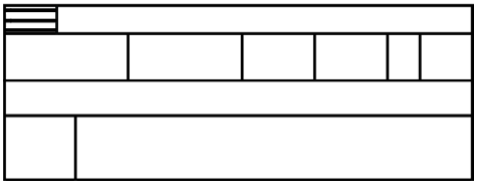
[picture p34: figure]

modula;n

Modulation

grip

Grip

9put & |tput left | Input and Output Left

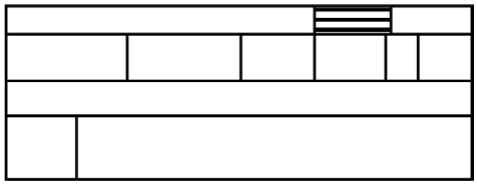
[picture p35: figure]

DC IN | Ext CLK | CV In
| IN

ext clk 9 cv 9

Gate In

dc 9 | gate |

## 9put `& |tput "r Input and Output Right

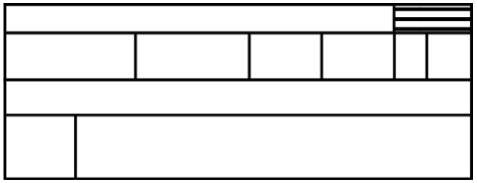
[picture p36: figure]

CV Out

cv |

Gate Out

gate |

Phones

ph"os |tput

Output

## tune & modulator Tune and Modulator

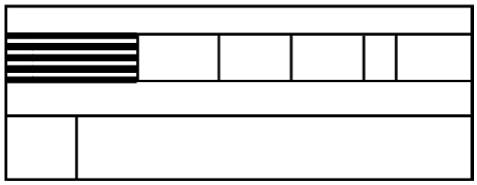
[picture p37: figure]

tune

Tune

lfo_/c
lk rate

LFO/CLK Rate

wave =m

Wave Form

noise

r&om

vco VCO

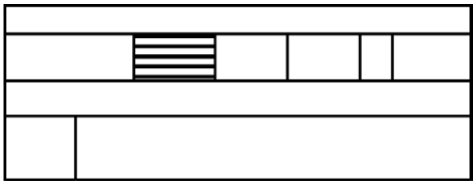
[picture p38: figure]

MOD | Range | Pulse Width
mod | range

#af

#h #d

#b

pulse wid?

lfo

manual

5v

## s|rce mix} Source Mixer

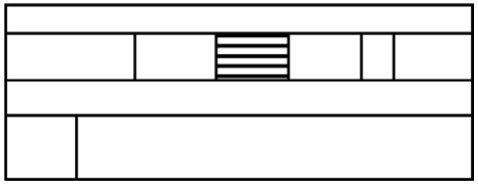
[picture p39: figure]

Sub OSC | Noise
sq | sw | sub osc | noise

#aoct d{n

#boct d{n

#boct d{n

vcf VCF

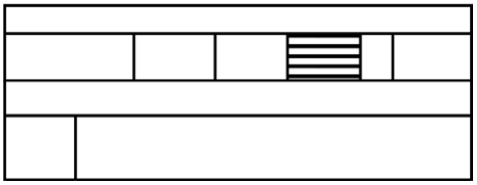
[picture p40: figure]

FREQ | RES | ENV | MOD | KYBD
freq | res | 5v | mod | kybd

vca VCA

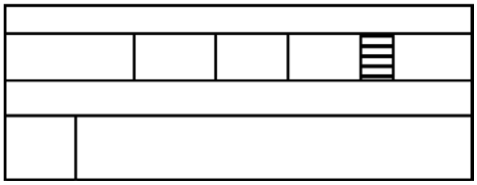
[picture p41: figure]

5v

gate

ENV

Gate

## 5v ENV

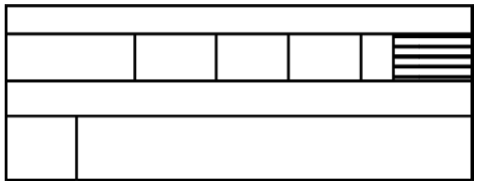
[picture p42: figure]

gate & trig

gate
lfo
A | D | S | R
a | d | s | r

Gate +Trig
Gate
LFO

middle sec;n | Middle Section

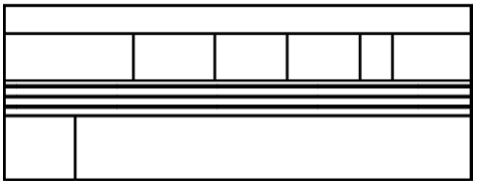
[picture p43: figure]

p{} | load play | d{n u`&d up | hold key
trans
pose
sequ;er | >pe7io | legato | re/
Power | Load | Play | U&D | Up Down Hold | Key Transpose
Sequencer | Arpeggio | Legato | Rest

## l{} left Lower Left

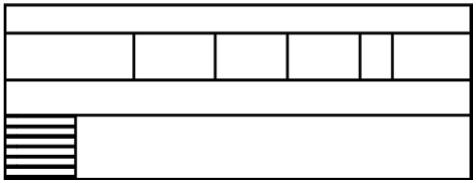
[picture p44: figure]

VCO

Volume | Portamento
Auto | Off | On
L | M | H

Transpose

Bender

VCF

Bender

LFO
MOD

b5d}

vco vcf lfo
mod
volume | porta;to

transpose

b5d}

auto (f on

l m h

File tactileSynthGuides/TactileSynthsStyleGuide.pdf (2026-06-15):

## TactileSynths Style Guide

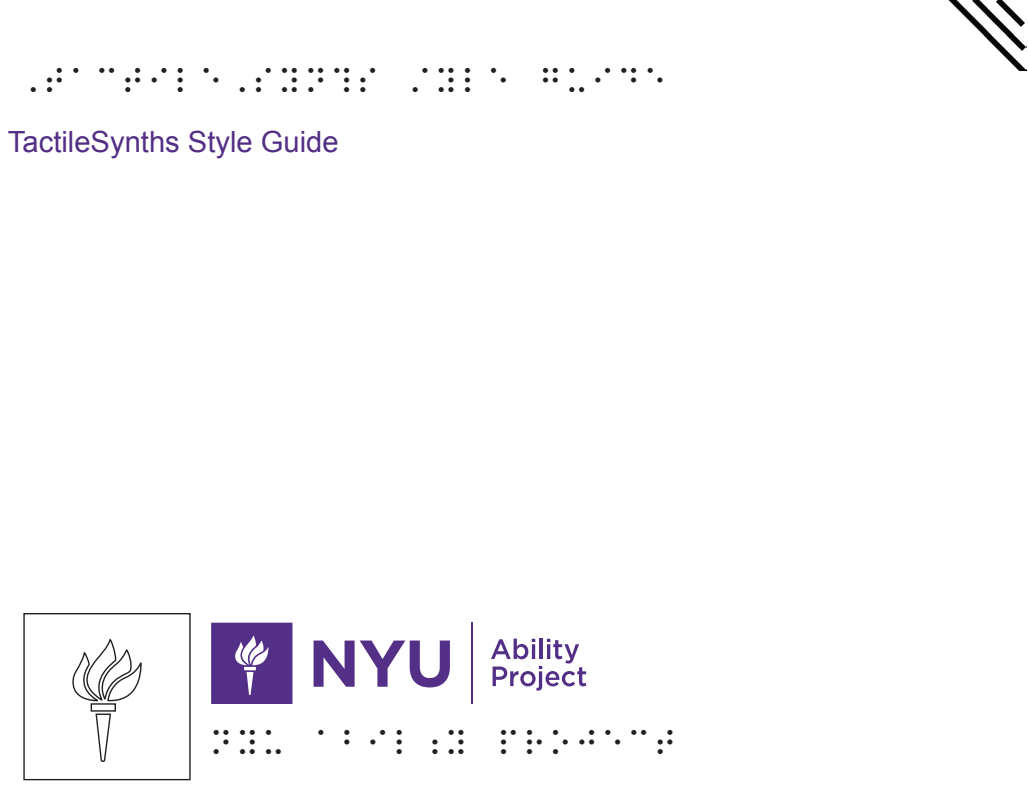
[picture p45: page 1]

,tactile,syn?s /yle guide

nyu abil;y project

## TactileSynths NYU Ability Project / IDM

Created by:
Stefanie Koseff, Faculty Lead Madeline Mau
Moira Zhang
Ciarra Black
Izabella Rodrigues
Jason Wallach
Lauren Race
R. Luke DuBois, Faculty Advisor

tactile syn?s
nyu abil;y project
_/ idm

created by:
stefanie koseff,
faculty lead
madeline mau
moira zhang
ciarra black
izabella rodrigues
jason wallach
lauren race
r. luke dubois,
faculty advisor tactile syn?s ~c #bjbe new york univ}s;y is lic;ed "u cc by-nc-sa #d4j4 ,to view a copy ( ? lic;e¹ visit
https³_/_/cr¹tivecommons4org_/li c5ses_/by-nc-sa_/#d4j_/

,"p ( ! syn? a³ess project4 ,git,hub³
https³_/_/gi?ub4com_/idmnyu_/syn?a³ess

Tactile Synths © 2025 New York University is licenced under CC BY-NC-SA 4.0.
To view a copy of this licence, visit
https://creativecommons.org/licenses/by-nc-sa/4.0/

Part of the Synth Access Project.
GitHub: https://github.com/IDMNYU/synthaccess

## Fonts, Colors and Symbols

fonts¹ colors & symbols

Purple:
Hex # 532e85

Black:
Hex # 000000

purple³ hex_? #ecb;e#he

black³ hex_? #jjjjjj

colors

## Colors

fonts³ | Fonts: Print title: Arial 21pt Print body: Arial 14pt Braille title: Swell Braille 26pt Braille body: Swell Braille 24pt

pr9t title³ >ial #bapt
pr9t body³ >ial #adpt
brl title³ swell brl #bfpt brl body³ swell brl #bdpt

## Symbols:

Use 2.0 pt width line stroke

symbols³
use #b4j wid? l9e /roke

key | Key:
|tput | Output

9put Input

bidirec;nal jack Bidirectional Jack

v}tical slid} Vertical Slider

horizontal slid} Horizontal Slider

or | swit* | Switch
or

Key: Key:

knob Knob

button Button

Square Button

Power Switch

squ>e button

p{} swit*

Key: Key:

st - sawtoo? ST - Sawtooth

Rising Saw

Falling Saw

tri - triangle TRI - Triangle

s9e Sine

adsr ADSR

pls - pulse

squ>e

PLS - Pulse

SQ - Square

ris+ saw

fall+ saw

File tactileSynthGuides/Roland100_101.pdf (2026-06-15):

## Roland System-100 Model-101

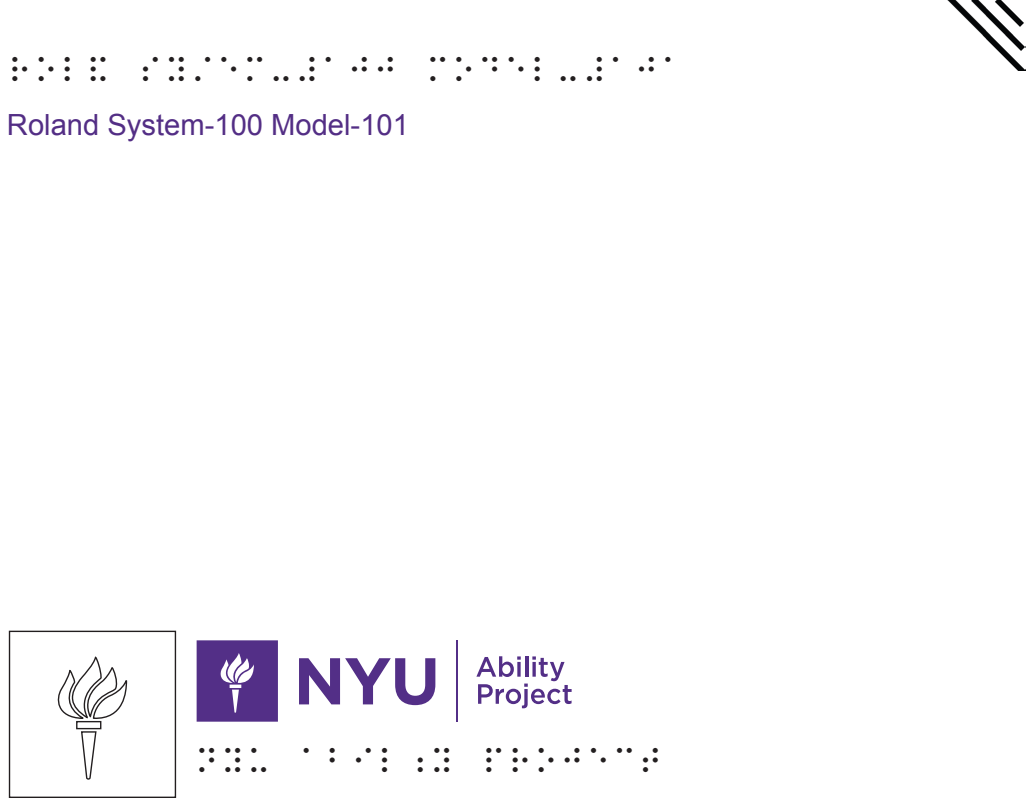
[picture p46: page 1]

rol& sy/em-#ajj model-#aja

nyu abil;y project

## Tactile Synths NYU Ability Project / IDM

Created by:
Stefanie Koseff, Faculty Lead Madeline Mau
Moira Zhang
Ciarra Black
Izabella Rodrigues
Jason Wallach
Lauren Race
R. Luke DuBois, Faculty Advisor

tactile syn?s
nyu abil;y project
_/ idm

created by:
stefanie koseff,
faculty lead
madeline mau
moira zhang
ciarra black
izabella rodrigues
jason wallach
lauren race
r. luke dubois,
faculty advisor tactile syn?s ~c #bjbe new york univ}s;y is lic;ed "u cc by-nc-sa #d4j4 ,to view a copy ( ? lic;e¹ visit
https³_/_/cr¹tivecommons4org_/li c5ses_/by-nc-sa_/#d4j_/

,"p ( ! syn? a³ess project4 ,git,hub³
https³_/_/gi?ub4com_/idmnyu_/syn?a³ess

Tactile Synths © 2025 New York University is licenced under CC BY-NC-SA 4.0.
To view a copy of this licence, visit
https://creativecommons.org/licenses/by-nc-sa/4.0/

Part of the Synth Access Project.
GitHub: https://github.com/IDMNYU/synthaccess

Key: Key:

,|tput Output

,9|t Input

bidirec;nal jack | Bidirectional Jack
v}tical slid} | Vertical Slider

horizontal slid} Horizontal Slider

or | swit* | Switch
or

ROLAND 100_101
DRAFT 1 05/29/26

Key: Key:

knob Knob

button Button

Square Button

Power Switch

squ>e button

p{} swit*

Key: Key:

st - sawtoo? ST - Sawtooth

Rising Saw

Falling Saw

tri - triangle TRI - Triangle

s9e Sine

adsr ADSR

pls - pulse

squ>e

PLS - Pulse

SQ - Square

ris+ saw

fall+ saw

## Phones

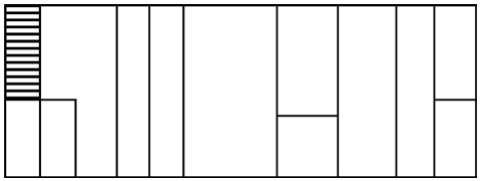
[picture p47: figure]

Level

Phones

ph"os

ph"os

level

## Power

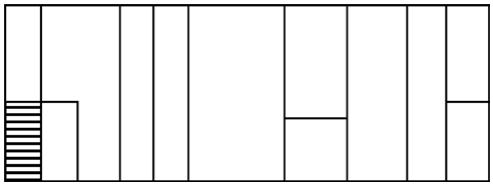
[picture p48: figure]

Power

p{}

p{}

## Glide

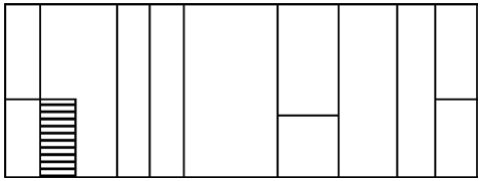
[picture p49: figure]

Auto Glide

Glide Manual

glide

auto glide

glide manual

## Envelope Generator/ ADSR

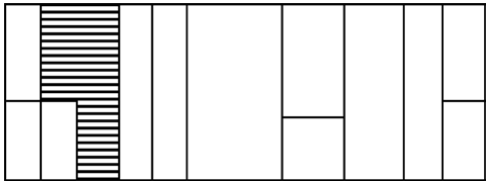
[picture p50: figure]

A

ADSR

D | S | R

Ext. Gate

LFO | Ext. Env.

KBD Gate

5velope g5}ator_/adsr

A | D | S | R

ext gate adsr

kbd gate ext 5v

lfo

## Low Frequency Oscillator

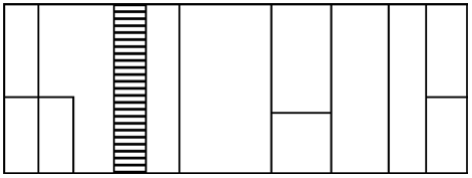
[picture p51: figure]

LFO Frequency

LFO

l{ frequ5cy oscillator

lfo frequ5cy

sawtoo?

s9e

squ>e

lfo

## keybo>d 3trol voltage Keyboard Control Voltage

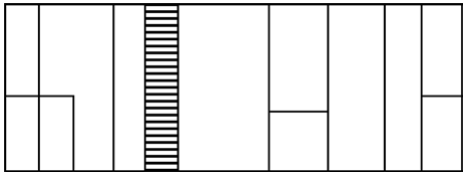
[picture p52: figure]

KBD Gate

KBD CV

Checkpoint

Portamento

kbd gate

kbd cv

porta;to

*eckpo9t

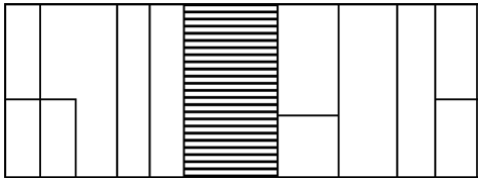
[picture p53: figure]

Ext. CV | Ext. CV | LFO

ADSR

Pulse Width

Manual
LFO

VCO Sync

VCO

## Voltage Controlled Oscillator

voltage 3troll$ oscillator

wave =m

Fine Tuning | Frequency | Waveform
f9e tun+ | frequ5cy

vco

ext cv

ext cv lfo

adsr
manual
lfo

pulse wid?

## Audio Mixer

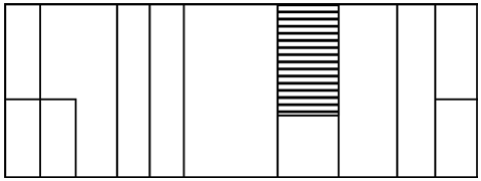
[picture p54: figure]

Ext. Input | VCO | Noise

audio mix}

ext 9put vco noise

## Noise Generator

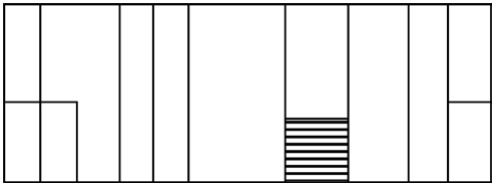
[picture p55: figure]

Noise
White

Pink

noise g5}ator

:ite

p9k

## High Pass Filter / Voltage Controlled Filter

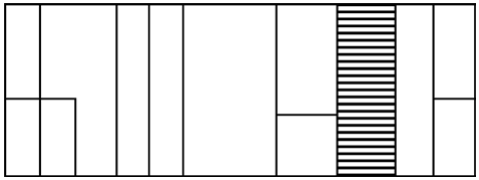
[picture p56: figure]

LFO

Ext. CV

Checkpoint
KBD CV | ADSR
HPF Cutoff | VCF Cutoff | Resonance

hi< pass filt}_/voltage 3troll$ filt}

hpfcut(f vcf cutoff reson.e

Ext.

ext cv

lfo

ext kbd cv adsr

## Voltage Controlled Amplifier

LFO

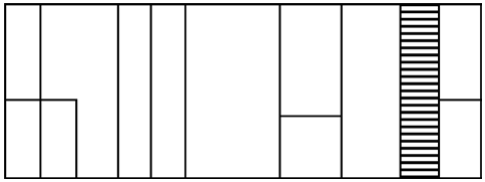
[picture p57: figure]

Initital gain

ADSR

voltage 3troll$ amplifi}

Checkpoint

9itial ga9

lfo adsr

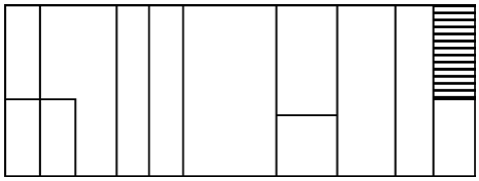
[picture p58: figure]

High

Low

## hi< |tput_/l{ |tput High Output / Low Output

hi<

l{

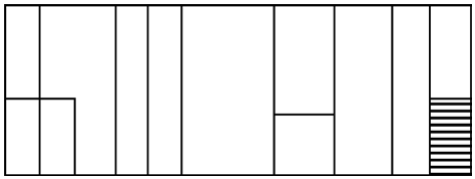
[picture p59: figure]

Level

## Standard Oscillator A-440Hz

standard oscillator a-440hz

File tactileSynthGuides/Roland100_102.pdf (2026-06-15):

## Roland System-100 Model-102

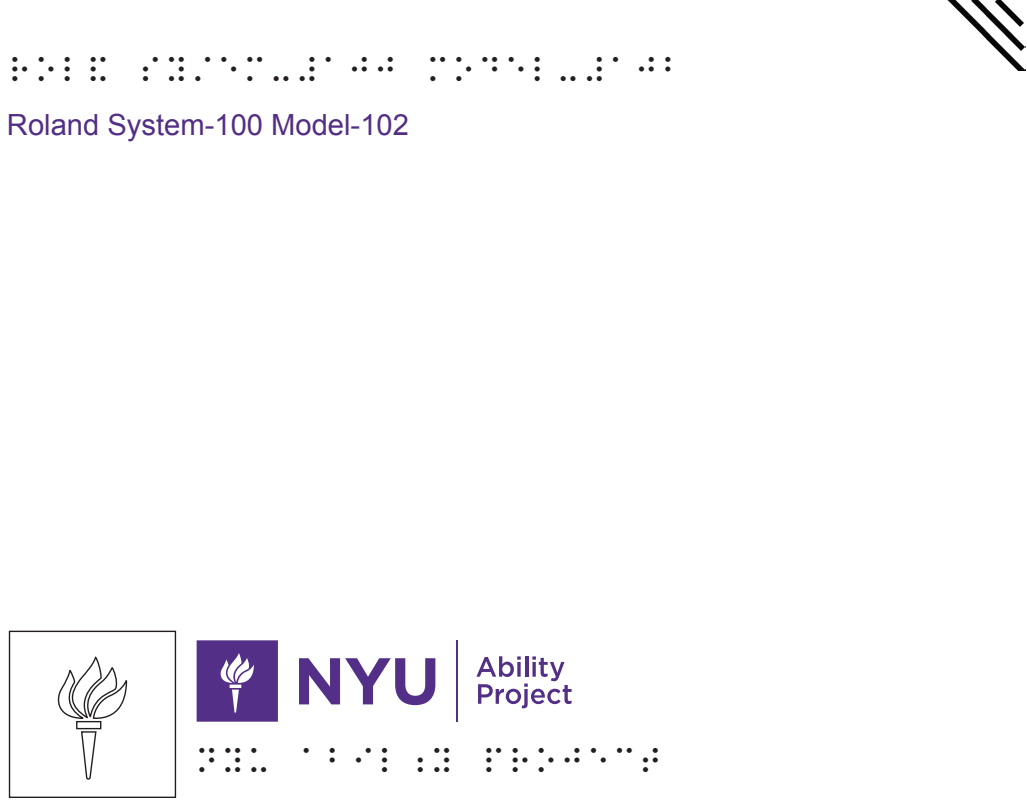
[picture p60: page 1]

rol& sy/em-#ajj model-#ajb

nyu abil;y project

## Tactile Synths NYU Ability Project / IDM

Created by:
Stefanie Koseff, Faculty Lead Madeline Mau
Moira Zhang
Ciarra Black
Izabella Rodrigues
Jason Wallach
Lauren Race
R. Luke DuBois, Faculty Advisor

tactile syn?s
nyu abil;y project
_/ idm

created by:
stefanie koseff,
faculty lead
madeline mau
moira zhang
ciarra black
izabella rodrigues
jason wallach
lauren race
r. luke dubois,
faculty advisor tactile syn?s ~c #bjbe new york univ}s;y is lic;ed "u cc by-nc-sa #d4j4 ,to view a copy ( ? lic;e¹ visit
https³_/_/cr¹tivecommons4org_/li c5ses_/by-nc-sa_/#d4j_/

,"p ( ! syn? a³ess project4 ,git,hub³
https³_/_/gi?ub4com_/idmnyu_/syn?a³ess

Tactile Synths © 2025 New York University is licenced under CC BY-NC-SA 4.0.
To view a copy of this licence, visit
https://creativecommons.org/licenses/by-nc-sa/4.0/

Part of the Synth Access Project.
GitHub: https://github.com/IDMNYU/synthaccess

key | Key:
|tput | Output

9put Input

bidirec;nal jack | Bidirectional Jack
v}tical slid} | Vertical Slider

horizontal slid} Horizontal Slider

or | swit* | Switch
or

ROLAND 100_102
DRAFT 1 05/29/26

Key: Key:

knob Knob

button Button

Square Button

Power Switch

squ>e button

p{} swit*

Key: Key:

st - sawtoo? ST - Sawtooth

Rising Saw

Falling Saw

tri - triangle TRI - Triangle

s9e Sine

adsr ADSR

pls - pulse

squ>e

PLS - Pulse

SQ - Square

ris+ saw

fall+ saw

## ph"os_/p{} Phones / Power

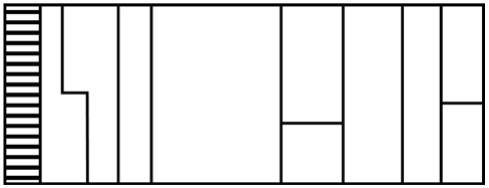
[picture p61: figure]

Level

ph"os | Phones

level

p{} | Power

sample `& hold Sample & Hold

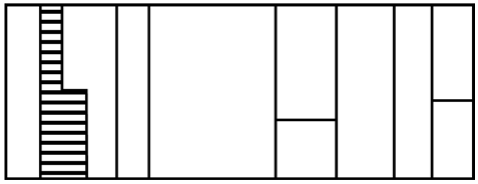
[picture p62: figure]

sample "t

|tput lag

Sample Time
S & H | Clock | Ext
Output Lag | Sample Mode

sample mode

(f

Off | Ext. ext
s`&h | clock | ext

ADSR | ADSR
a | d | s | r

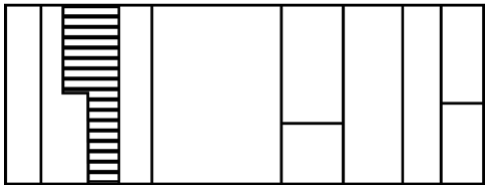
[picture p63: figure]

A | D | S | R

5velope g5}ator
Envelope Generator

kbd gate
KBD Gate | ADSR
KBD CV | Ext Env

kbd cv

adsr

ext 5v

l{ frequ5cy oscillator

## Low Frequency Oscillator

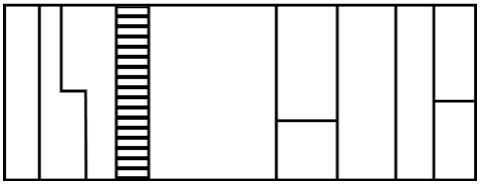
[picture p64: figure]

lfo frequ5cy

LFO Frequency

## Voltage Controlled Oscillator (top)

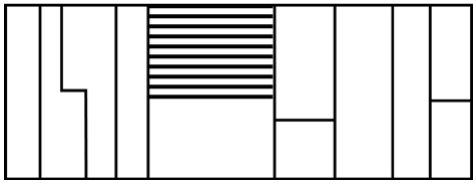
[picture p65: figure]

f9e tun+ | frequ5cy | wave =m

Fine Tuning

VCO Sync

Weak | Strong | VCO

Frequency

| | Wave Form

vco sync

w¹k | /r;g

voltage 3troll$ oscillator "<top">

vco voltage 3troll$ oscillator "<bottom">

## Voltage Controlled Oscillator (bottom)

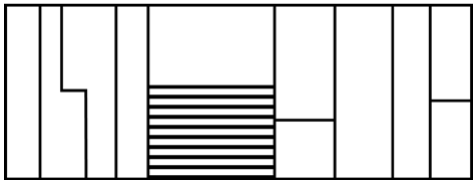
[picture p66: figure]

s`&h

s`&h

ext cv

Ext CV

S & H

S & H

lfo
LFO

adsr
manual

lfo

Manual

pulse wid? mod

Pulse Width Mod

pulse wid?
Pulse Width

## audio mix} Audio Mixer

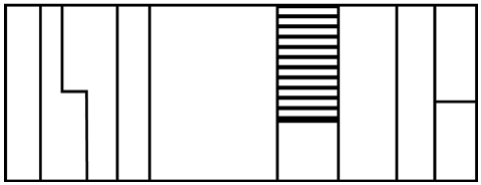
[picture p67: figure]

ext 9put | vco | r+ mod
Ext Input | VCO | Ring Mod

## r+ modulator Ring Modulator

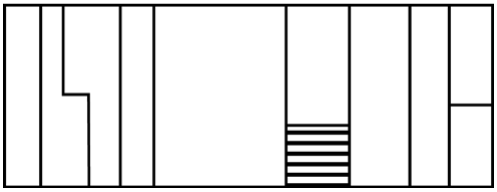
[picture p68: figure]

rm
R M | Ext

Ext

LFO

| ext

ext

lfo hi< pass filt}/voltage 3troll$ filt}

## High Pass Filter / Voltage Controlled Filter

input or output?

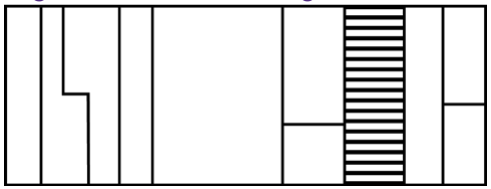
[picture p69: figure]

hpf cut(f
frequ5cy

vcf cut(f
frequ5cy

reson.e

ext

lfo | ext
HPF Cutoff Frequency | VCF Cutoff Frequency | Resonance

Ext

Ext

Checkpoint

KBD CV | ADSR
LFO | kbd cv adsr *eckpo9t

voltage 3troll$ amplifi}

## Voltage Controlled Amplifier

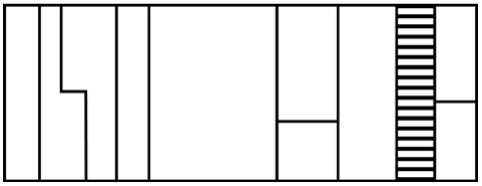
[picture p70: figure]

Initial Gain

LFO | ADSR

input or output?

Checkpoint

*eckpo9t

9itial ga9

lfo adsr

## hi<_/l{ |tput High/Low Output

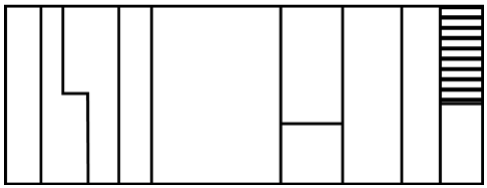
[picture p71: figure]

hi< |tput

l{ |tput

High Output

Low Output

## mix} Mixer

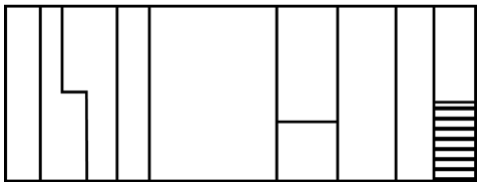
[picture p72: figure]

9put

Input

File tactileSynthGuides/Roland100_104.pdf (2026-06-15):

## Roland System-100 Model-104


rol& sy/em-#ajj model-#a-#ajd

nyu abil;y project

## Tactile Synths NYU Ability Project / IDM

Created by:
Stefanie Koseff, Faculty Lead Madeline Mau
Moira Zhang
Ciarra Black
Izabella Rodrigues
Jason Wallach
Lauren Race
R. Luke DuBois, Faculty Advisor

tactile syn?s
nyu abil;y project
_/ idm

created by:
stefanie koseff,
faculty lead
madeline mau
moira zhang
ciarra black
izabella rodrigues
jason wallach
lauren race
r. luke dubois,
faculty advisor tactile syn?s ~c #bjbe new york univ}s;y is lic;ed "u cc by-nc-sa #d4j4 ,to view a copy ( ? lic;e¹ visit
https³_/_/cr¹tivecommons4org_/li c5ses_/by-nc-sa_/#d4j_/

,"p ( ! syn? a³ess project4 ,git,hub³
https³_/_/gi?ub4com_/idmnyu_/syn?a³ess

Tactile Synths © 2025 New York University is licenced under CC BY-NC-SA 4.0.
To view a copy of this licence, visit
https://creativecommons.org/licenses/by-nc-sa/4.0/

Part of the Synth Access Project.
GitHub: https://github.com/IDMNYU/synthaccess

key | Key:
|tput | Output

9put Input

bidirec;nal jack | Bidirectional Jack
v}tical slid} | Vertical Slider

horizontal slid} Horizontal Slider

or | swit* | Switch
or

R O L A N D 1 0 0 _ 1 0 4
DRAFT 1 05/29/26

Key: Key:

knob Knob

button Button

Square Button

Power Switch

squ>e button

p{} swit*

Key: Key:

st - sawtoo? ST - Sawtooth

Rising Saw

Falling Saw

tri - triangle TRI - Triangle

s9e Sine

adsr ADSR

pls - pulse

squ>e

PLS - Pulse

SQ - Square

ris+ saw

fall+ saw

## p{}_/|tputs Power / Outputs

Power

Gate | Series

Parallel
Ch A Ch B

p{}

gate | s}ies | p>allel ch a ch ;b

gate "t_/clock rate | Gate Time / Clock Rate
gate "t | clock rate

range

Gate Time

Ext CV Input

Clock Rate

Range

m9 | max

#ej.0

ext cv 9put

50%

Min | Max | 0

x1

10

x10

#j

x#a

#aj

x#aj

/ep numb} | Step Number
One Time | Ch A

Step Number

1

4

7

10

Repeat | Ch B

"o "t

rep¹t

/ep numb}

#a

#d

#g

#aj

ch a

ch ;b

## />t 3t9ue /op /ep Start Continue Stop Step

ext
trig

/>t

Start

Ext Trig Input | Ext Trig Input | End Pulse Output | Ext Trig Input

ext
trig

³t9ue

Continue

/op

5d pulse

Stop

ext
trig

step

Step

range #a-#d | Range 1-4
range | range

Range

5V | 5V
2.5V | 2.5V 10V | 10V

Range

Channel A | Channel B

*annel a

#b4e,v | #b4e,v

#e,v | #e,v

#aj,v | #aj,v

*annel ;b

#a

#b

#c

#d | #d #c

#b

1 | #a | 1
2 | | 2
3 | | 3
4 | | 4

range #e-#ab Range 5-12

#e | 5 | #e

6

7

8

9

10

11

12 | 12
| 10

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
#ab | #ab #aa

#aj

#i

#h

#g

#f

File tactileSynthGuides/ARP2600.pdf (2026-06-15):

>p #bfjj; ARP 2600

nyu abil;y project

## Tactile Synths NYU Ability Project / IDM

Created by:
Stefanie Koseff, Faculty Lead Madeline Mau
Moira Zhang
Ciarra Black
Izabella Rodrigues
Jason Wallach
Lauren Race
R. Luke DuBois, Faculty Advisor

tactile syn?s
nyu abil;y project
_/ idm

created by:
stefanie koseff,
faculty lead
madeline mau
moira zhang
ciarra black
izabella rodrigues
jason wallach
lauren race
r. luke dubois,
faculty advisor tactile syn?s ~c #bjbe new york univ}s;y is lic;ed "u cc by-nc-sa #d4j4 ,to view a copy ( ? lic;e¹ visit
https³_/_/cr¹tivecommons4org_/li c5ses_/by-nc-sa_/#d4j_/

,"p ( ! syn? a³ess project4 ,git,hub³
https³_/_/gi?ub4com_/idmnyu_/syn?a³ess

Tactile Synths © 2025 New York University is licenced under CC BY-NC-SA 4.0.
To view a copy of this licence, visit
https://creativecommons.org/licenses/by-nc-sa/4.0/

Part of the Synth Access Project.
GitHub: https://github.com/IDMNYU/synthaccess

key³ | Key:
|tput | Output

9put Input

bidirec;nal jack | Bidirectional Jack
v}tical slid} | Vertical Slider

horizontal slid} Horizontal Slider

or | swit* | Switch
or

## key³ Key:

knob Knob

button Button

st - sawtoo? ST - Sawtooth

tri - triangle TRI - Triangle

s9e Sine

pls - pulse

sq - squ>e

PLS - Pulse

SQ - Square

adsr ADSR preamplifi} _/ 5velope foll{} _/

## r+ modulatorPreamplifier / Envelope Follower / Ring Modulator


pre amp | vco#a | vco#b

audio

dc

## Pre Amp preamp

5v foll

## Env Foll

r+ mod

## Ring Mod

Pre Amp | VCO 1

DC

Audio

VCO 2

vco-#a | VCO-1


frequ5cy | Frequency
f9e tune | Fine Tune

## VCO-1 vco-#a


kbd

KBD

s_/h

S/H

vco#b

VCO 2

adsr

ADSR

ST

pls

ST

PLS

LFO
LFO

vco-#b VCO-2

frequ5cy | Frequency
f9e tune | Fine Tune

VCO-2 vco-#b

ST

pls

pulse wid?

tri

s9e

Pulse Width

kbd

KBD

adsr

VCO1

noise

Noise

vco#a

ADSR

s_/h

S/H

TRI | ST
SINE | PLS

LFO
LFO

vco-#c VCO-3

frequ5cy | Frequency
f9e tune | Fine Tune

## VCO-3 vco-#c

ST

pls

pulse wid? | Pulse Width

ADSR

vco#b

VCO2

kbd | adsr

KBD

ST

PLS

LFO
LFO

s_/h

S/H

VCF | VCF
frequ5cy | Frequency
f9e tune | Fine Tune
reson.e | Resonance

r+mod

Ring Mod

vco#a

VCO 1

vco#b

VCO 2

vco#c

VCO 3

noise

Noise

vco#b

VCO 2

adsr

ADSR

## VCF VCF

kbd

KBD

adsr_/> ADSR/AR

trig
Trig

gate
Gate

s_/hgate

## ADSR/AR

attack
rel¹se

/>t

kbd gate_/trig

S/H Gate

A | D | S | R
a | d | s | r

Release

Start Attack

KBD Gate /Trig

adsr_/>

voltage 3troll$ amplifi}

9itial ga9 | Initial Gain

VCF

VCF

adsr

ADSR

AR

AR

## VCA VCA

r+ mod

RINGMOD

## Voltage Controlled Amplifier

mix} _/ rev}b}ator

Pan

VCF
VCF

mix}
Mixer

vca
VCA

## Mixer / Reverberator

left

rev}b}ator

reverb

pan

reverb

Left | left | "r

## Mixer

"r

Right

## Reverberator

Reverb

Right

Left

## Left Speaker

left sp¹k}; Multiples; kbd; multiples; KBD; sp¹k}; Speaker; left; sp¹k} Left Speaker

## noise g5}ator Noise Generator

noise g5}ator

## Noise Generator

:ite

p9k

lf

White

Pink

LF | m9
max | Max

Min voltage processors Voltage Processors

Inverter

LAG

Inverter

#b

#d

#f

#g

#a

#c

#e

9v}t}

9v}t}

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
## sample & hold Sample and Hold

noise; 9t clock; ext clock; level; Rate; sample & hold; electronic; swit*; Noise; Int Clock; Ext Clock; Level; Electronic; Switch

Sample and Hold

## "r sp¹k} Right Speaker

"rsp¹k}

/}eo ph"os

p{}

sp¹k}
Speaker

Right Speaker

Power

Stereo Phones

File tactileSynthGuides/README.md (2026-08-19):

# tactileSynthGuides

#### tactilesyn?guides

Part of [synthaccess](../README.md)

[ABILITY Project](http://ability.nyu.edu) / [Integrated Design & Media](http://idm.engineering.nyu.edu)   
New York University

Files:
- README.md - this file
- [Style Guide](TactileSynthsStyleGuide.pdf) - PDF style guide
- [ARP 2600](ARP2600.pdf) - tactile guide for the ARP 2600 / The Human Comparator TTSH
- [Roland SH-101](RolandSH_101.pdf) - tactile guide for the Roland SH-101 / Superlative SB01
- [Roland 100 Model 101](Roland100_101.pdf) - tactile guide for the Roland 100 Series Model 101
- [Roland 100 Model 102](Roland100_102.pdf) - tactile guide for the Roland 100 Series Model 102
- [Roland 100_Model 104](Roland100_104.pdf) - tactile guide for the Roland 100 Series Model 104
- [Serge 73-75](Serge7375.pdf) - tactile guide for the Serge Modular 73-75 Panels
- elements - folder of EPS and SVG tactile elements for standard synthesizer affordances
- elements/serge - folder of EPS and SVG tactile elements for Serge synthesizers (matched with [tactileModular](../tactileModular))

**tactileSynthGuides** consist of a collection of tactile guides and standards for synthesizers. These are currently designed to be printed using swell-form or UV printing as little booklets, with the goal of allowing a B/LV user to "feel" the synthesizer interface as a spatial map on a page while working with the physical hardware. 

We provide a standard vocabulary of tactile symbols in the Style Guide and the elements folder - for example, different crosshatch patterns to give different feels for inputs and outputs on modular systems. These are especially useful for legacy (non-MIDI-aware) synthesizers that have a densely packed physical interface; conceptually, tactile guides are one of the only ways to do accessibility with things like Eurorack-format modular equipment where the affordance space is too small to accommodate braille.

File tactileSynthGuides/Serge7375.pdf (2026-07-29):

## Serge Modular 73-75 Panels


s}ge modul> #gc-#ge panels

nyu abil;y project

## Tactile Synths NYU Ability Project / IDM

Created by:
Stefanie Koseff, Faculty Lead Madeline Mau
Moira Zhang
Ciarra Black
Izabella Rodrigues
Jason Wallach
Lauren Race
R. Luke DuBois, Faculty Advisor

tactile syn?s
nyu abil;y project
_/ idm

created by:
stefanie koseff,
faculty lead
madeline mau
moira zhang
ciarra black
izabella rodrigues
jason wallach
lauren race
r. luke dubois,
faculty advisor

panel guide panel guide

voice
VOICE

osc OSC

osc OSC

tws
TWS

vcf
VCF

vca VCA

vca VCA

ring
RING

env
ENV

adp
ADP
control
CONTROL

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
prc PRC

ssg
SSG
homebuilt#a HOMEBUILT #1

osc OSC

tws
TWS

p&t
P&T

com
COM

prc PRC

vca VCA

ring
RING

rvb
RVB

pre
PRE
homebuilt#b
HOMEBUILT #2

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
preset
PRESET

seq
SEQ

prg
PRG

tbs
TBS

# table ( 3t5ts table of contents

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
ring
RING

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
misc 9; misc in; trs 9; trs in; ac out; misc |; misc out; trs |; trs out; basic knob; dc out; (fset "6 knob; offset (+) knob; pulse 9; pulse in; scale "8 knob; scale (×) knob; pulse |; pulse out; button

KEY
symbol key

ADP ADP; adapt} adapter; a out; b out; c out; a thresh; b thresh; c thresh

COM
triple comp>ator
triple comparator

end; out; window; start in; window +; cycle; hold; window vc; dura;n vc; duration vc; rise; fall; dura;n "8; duration ×

ENV
5velope g5}ator envelope generator

a out; a end; b out; b end

NEG
negative slew

:ite; white; pink; /epp$ ac; stepped ac; /epp$ dc; stepped dc; manual; tri7}; trigger

NOI
noise s|rce noise source

OSC OSC; oscillator oscillator; sine ac; sine dc; wave%ape; waveshape; saw dc; saw ac; sync; frequ5cy; frequency

p¹k |; peak out; trough out; p¹k 9; peak in; trough in

p¹k `& tr|< peak & trough

a out; a start; a high; a sustain; a end; b out; b start; b high; b sustain; b end

POS
positive slew

a out; b out

PRC
dual processor

PRE PRE
preamplifi}

### preamplifier

9put

input

ga9

gain

out

out

#aj 10

PRG (¹/³) PRG (1/3) programm} programmer; 1 out; 2 out; 3 out; 4 out; select

PRG (2/³) PRG (2/3) programm} programmer; 5 out; 6 out; 7 out; 8 out; select

PRG (³/³) PRG (3/3) programm} programmer; all |; all out; cv a out; cv b out; cv c out

RING RING; r+ modulator ring modulator; out; RVB RVB; rev}b}ator reverberator; mix; wet

5 out; 6 out; 4 out; 7 out; 3 out; 8 out; 2 out; 9 out; 1 out; 10 out; clock; hold; reset; step

SEQ
sequ;er sequencer

smoo? vc; smooth vc; smoo? |; smooth out; smoo? "8; smooth ×; cycle; smoo? 9; smooth in; smoo? "6; smooth +; hold; coupler; /epp$ vc; stepped vc; sample; /epp$ "8; stepped ×; /epp$ 9; stepped in; /epp$ "6; stepped +; /epp$ |; stepped out

SSG
smoo? `& /epp$ g5}ator
smooth & stepped generator

select

TBS
bi-direc;nal r|t}
bi-directional router

a out; b out; c out; VCA VCA; gate gate; out; lin; log; gain

TWS
triple wave%ap} triple waveshaper

VCF VCF

### filt} filter

hi<

high

hi<

high

b&

band

b&

band

l{

low

l{

low

q

Q

9put

input

freq vc

freq vc

ga9

gain

freq "8

freq ×

frequ5cy

frequency

#ai 19

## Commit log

2025-11-06 listen to nrpn on device 2
2025-11-06 select midi device to read nrpm
2026-04-09 initial STEP files
    [pulseInTriangle.step, pulseOutTriangle.step]
2026-04-13 added 8 step files
    [AC_InCircle.step, AC_OutCircle.step, DC_InSquare.step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]
2026-04-13 added STL versions
    [AC_InCircle.stl, AC_OutCircle.stl, DC_InSquare.stl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]
2026-06-26 Better Mod Checks
    Improved mod destination checking, and mod wheel checking.
2026-06-26 new devices
2026-10-06 Remove device name from devlist.txt
    I had removed this file, but the device name lingered on in this text list, which was inadvertently "leaking" something that we need to keep confidential.
